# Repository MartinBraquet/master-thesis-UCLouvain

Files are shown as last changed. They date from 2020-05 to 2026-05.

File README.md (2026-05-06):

# Master's thesis at UCLouvain

### Design of an ultra-low-power energy-harvesting audio sensor for ecosystem monitoring

Here are the source files of my Master's thesis at UCLouvain (June 2020).

It includes all the simulations required for this work:
* **Audio processing**: C code for the microcontroller and Matlab code to process the data (plot the graphs) received from the board
* **BOM**: Excel file with the bill of materials
* **IV mic**: Matlab code to plot the IV curves (current/voltage) of different microphones
* **Microcontroller**: Wisebatt simulation to provide a rough estimate of the whole system power consumption
* **Microphone**: LTspice and Matlab codes for the microphone/AFE subsystem (AC and noise)
* **PCB**: KiCad and Eagle files for the PCB design (schematic and PCB layout)
* **Power management**: Matlab and Excel files for measurements about the supercapacitor, solar cells, PMU and luminosity
* **Thesis source code**: LaTeX source code of the Master's thesis

Picture of the final model (with MCU/RF board)
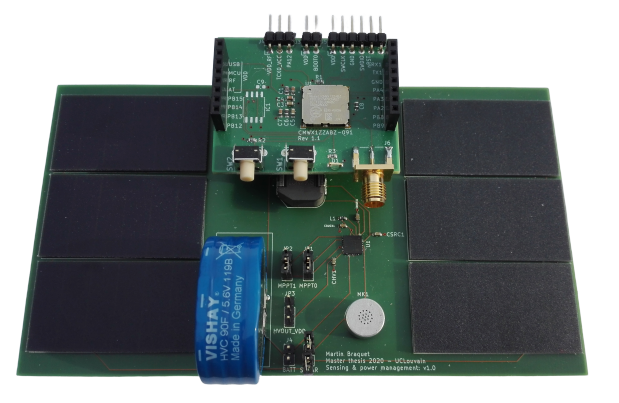
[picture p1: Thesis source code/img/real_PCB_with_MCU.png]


Precise spectrogram of the great tit song (from a bird song database)
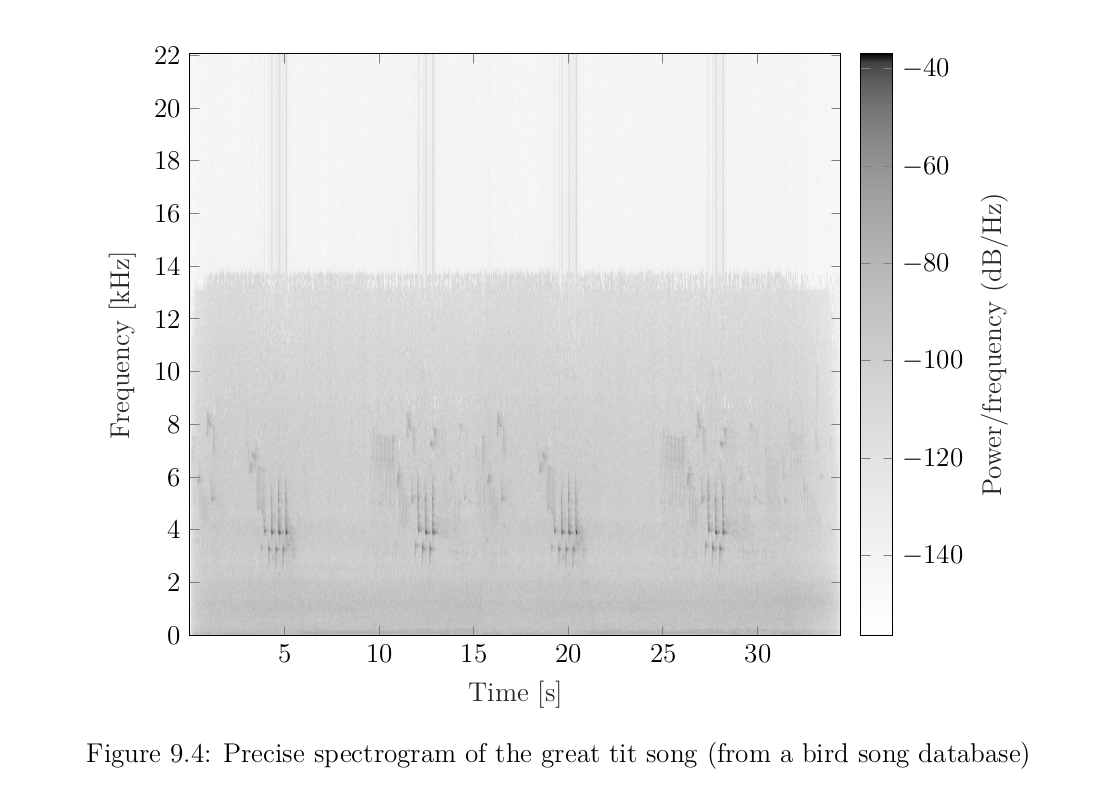
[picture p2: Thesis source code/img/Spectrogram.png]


Comparison of input-referred noise and current consumption for several operational amplifiers
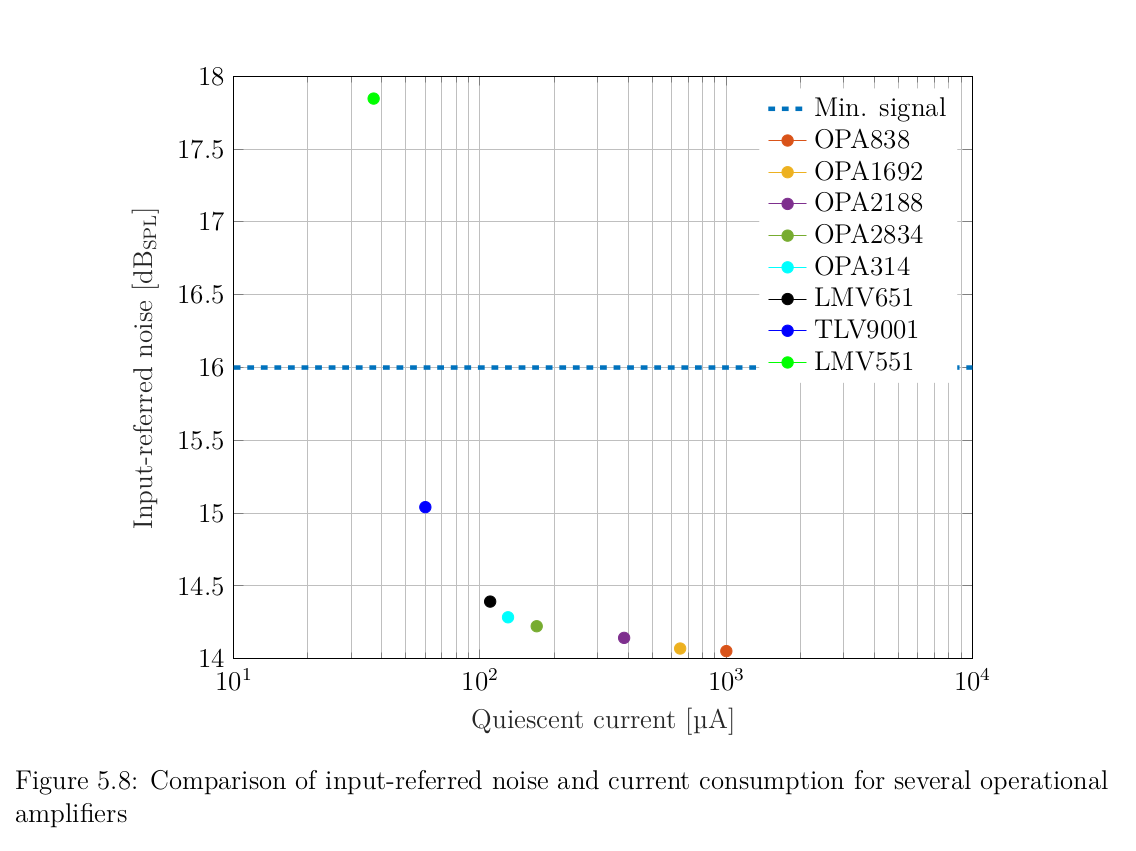
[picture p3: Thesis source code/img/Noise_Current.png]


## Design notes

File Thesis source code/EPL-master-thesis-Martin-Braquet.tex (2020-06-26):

% EPL master thesis covers template
\documentclass{EPL-master-thesis-covers-EN}

\usepackage{parskip}
\usepackage{siunitx}
\usepackage{float}
\usepackage{textcomp}
\usepackage{amsmath}
\usepackage{multirow}
\usepackage{subcaption}
\usepackage{pgfplots}
\usepackage{mathtools}
\usepackage{booktabs}
\pgfplotsset{compat=1.15}
\usepackage[hidelinks]{hyperref}
\definecolor{lttotitextcolor}{rgb}{0, 0.4, 0.25}
\usepackage{natbib}
\pdfoptionpdfminorversion=7

\graphicspath{{img/}}

\newgeometry{top=3cm,bottom=3cm,left=2cm,right=2cm}

\usepackage[americanresistors, RPvoltages, american voltages]{circuitikz}
\tikzstyle{sensor}=[draw, fill=blue!20, text width=5em, 
    text centered, minimum height=2.5em, rounded corners]
\tikzstyle{sensor2}=[draw, fill=green!20, minimum width=20em, 
    text centered, minimum height=2.5em, rounded corners]
\tikzstyle{sensor3}=[draw, fill=brown!20, text width=5em, 
    text centered, minimum height=2.5em, rounded corners]
\tikzstyle{sensor4}=[draw, fill=orange!20, text width=5em, 
    text centered, minimum height=2.5em, rounded corners]
\tikzstyle{empty_block}=[draw, minimum width=30em, 
    text centered, minimum height=12em, rounded corners]
\tikzstyle{empty_block2}=[draw, minimum width=10em, 
    text centered, minimum height=12em, rounded corners]
\tikzstyle{ann} = [above, text width=5em]
\tikzstyle{afes} = [draw, fill=red!20, text width=5em, 
    text centered, minimum height=2.5em, rounded corners]
\def\edgedist{2.5}

\usetikzlibrary{external}
\tikzexternalize
\tikzsetexternalprefix{tikz_figures/}

\newcommand{\parallelsum}{\mathbin{\!/\mkern-5mu/\!}}
\newcommand{\te}[1]{\textrm{#1}}
\newcommand{\tabitem}{~~\llap{\textbullet}~~}

\DeclarePairedDelimiter\floor{\lfloor}{\rfloor}

\newcommand\nnfootnote[1]{%
  \begin{NoHyper}
  \renewcommand\thefootnote{}\footnote{#1}%
  \addtocounter{footnote}{-1}%
  \end{NoHyper}
}

% Please fill in the following boxes
% Title of the thesis
\title{Design of an ultra-low-power energy-harvesting audio sensor for ecosystem monitoring}

% Subtitle - remove this line if not applicable
%\subtitle{Microphone design for biodiversity inventory in forest}

% Name of the student author(s)
\author{Martin \textsc{Braquet}\!\nnfootnote{\url{martin.braquet@hotmail.com}}}
%\secondauthor{Firstname \textsc{Lastname}}		% remove if not applicable
%\thirdauthor{Firstname \textsc{Lastname}}			% remove if not applicable

% Official title of the master degree (copy/paste from list below)
% Master [120] in Biomedical Engineering
% Master [120] in Chemical and Materials Engineering
% Master [120] in Civil Engineering
% Master [120] in Computer Science
% Master [120] in Computer Science and Engineering
% Master [120] in Cybersecurity
% Master [120] in Data Sciences Engineering
% Master [120] in Data Science: Information technology
% Master [120] in Electrical Engineering
% Master [120] in Electro-mechanical Engineering
% Master [120] in Mathematical Engineering
% Master [120] in Mechanical Engineering
% Master [120] in Physical Engineering
% Master [60] in Computer Science
% Specialised master in nanotechnologies
% Specialised master in nuclear engineering
\degreetitle{Master [120] in Electro-mechanical Engineering}

% Name of the supervisor(s)
\supervisor{David \textsc{Bol}}
\secondsupervisor{Ramin \textsc{Sadre}}		% remove if not applicable
%\thirdsupervisor{Firstname \textsc{Lastname}}		% remove if not applicable

% Name of the reader(s)
\readerone{Rémi \textsc{Dekimpe}}
\readertwo{Denis \textsc{Flandre}}			% remove if not applicable
%\readerthree{Firstname \textsc{Lastname}}			% remove if not applicable
%\readerfour{Firstname \textsc{Lastname}}			% remove if not applicable
%\readerfive{Firstname \textsc{Lastname}}			% remove if not applicable

% Academic year (update if necessary)
\years{2019--2020}

% Document
\begin{document}

% Front cover page
\hypersetup{pageanchor=false}

\maketitle

\begin{abstract}

The Internet of Things (IoT) is predicted to lead to the deployment of a very large number (possibly trillions) of connected smart sensors for various applications. Such a massive deployment of smart sensors is not environmentally sustainable if the smart sensors are replaced every two years because of the pressure they put on natural resources and the ecotoxicity of the e-waste they generate.

Furthermore, the rising climate change due to ecosystem destruction involves monitoring forests in order to analyze and preserve the ecosystem. Such monitoring is typically achieved manually via a person who samples data less than once a day, which fails to provide strong results and asks for human presence during data acquisition.

To solve these issues, the focus of this master thesis is on the development of an autonomous and efficient audio smart sensor continuously analyzing the forest ecosystem. To fulfill the energy constraints implied by its total autonomy, this sensor harvests energy from the environment through miniaturized photovoltaic cells sized according to the sun illuminance throughout days and seasons, using an environmentally-friendly and non-toxic supercapacitor to store energy.
With a 15+ year lifetime, this fully autonomous device operates at an optimized \SI{2.5}{V} supply voltage reaching \SI{22.1}{mW} of average power harvesting/consumption. An electret condenser microphone collects a signal as low as \SI{16}{dB_{SPL}} (compared to a \SI{14.22}{dB_{SPL}} input-referred noise), which is then amplified in the full frequency range of bird emission (\SI{20}{Hz} -- \SI{20}{kHz}) by a low-noise and low-power analog front-end. This signal is further processed in an ultra-low-power chip embedding a microcontroller, alternating between run and sleep modes with a $1/3$ duty cycle, and a transceiver optimized for IoT applications with LoRaWAN networks. 

The microcontroller detects sounds when birds are active (typically during the day for more than 12 hours) and ensures the radio-frequency communication at night depending on the supercapacitor voltage that is carefully monitored in real time. It sends information about the bird species encountered during the day, as well as their apparition frequency. In case of firmware update, this device receives the associated fragments when its energy is sufficient and it automatically changes the firmware with energy-optimized software requiring only \SI{10.6}{J} for the whole update.

By computing the weighted average frequency of the received sounds, the smart sensor is able to discriminate between four common birds in Belgium: the pigeon, blackbird, great tit and blue tit. For each species, several songs have been analyzed and used to train a $k$-nearest neighbors (KNN) classifier working in the real-time embedded system. Its precision, defined as the likelihood to find the correct species, reaches 94\% for songs coming from the previously learned database. For newly analyzed sounds, the detection algorithm performs likewise. More complex machine-learning algorithms could finally be further designed to discriminate between more species.

\end{abstract}

\renewcommand{\abstractname}{Acknowledgements}
\begin{abstract}

This thesis has been written throughout my last year at UCLouvain. It gave me the opportunity to have a first glimpse into an important work required for the procurement of a master's degree in engineering.  During this substantial work, I would like to thank the following people, starting with the most meaningful ones, for their important hints and source of motivation.

First of all, I would like to thank my main supervisor, Prof. D. Bol, for his precious advice. In his works, I deeply appreciated his way to approach a problem, starting with a technological/ecological/social need and then solving it by considering all the factors in the process (systemic approach). His maturity, sensibility and motivation to handle such problems made one of the most important marks on me throughout my studies at UCLouvain. 

Second, I would like to thank Tim Hess who wrote his thesis on a same topic but more focused on the wireless communication. We have had great collaborations to produce the final model of this work. He gave me important advice for the overall design and soldering of the PCB, more specifically on the handling of KiCad (a PCB design tool).

Third, I would like to thank the members of the ECS group\footnote{Electrical Circuits and Systems group led by Professors D. Bol and D. Flandre at UCLouvain.} and more specifically Rémi Dekimpe for his constant supervision through the year. He proved his availability at any time and had precious hints.

I would also like to thank my second supervisor, Prof. R. Sadre, for his availability. Likewise, I want to thank Prof. D. Flandre in advance for the reading of this thesis, as well as for his engaging courses given during my curriculum. More generally, I need to thank all the people who contributed to this work, e.g. for accessing the electronics lab and the ordering of the required materials.

\end{abstract}

\tableofcontents

\listoffigures

\listoftables

\newpage

\hypersetup{pageanchor=true}

\chapter{Introduction}

This thesis is dedicated to people interested in audio monitoring and its subsequent recent rise, as well as in the technical details/constraints related to the design of such sensors. It is accessible for people from diverse domains, but a background in engineering is nonetheless advised.

\section*{Context}

The Internet of Things (IoT) is a system of interrelated computing devices that are provided with unique identifiers and the ability to transfer data over a network without requiring human-to-human or human-to-computer interaction. It is predicted to lead to the deployment of a very large number (possibly trillions) of connected smart sensors for various applications. However, such a massive deployment of smart sensors is not environmentally sustainable if the smart sensors are replaced every two years because of the pressure they put on natural resources and the ecotoxicity of the e-waste they generate. Therefore, it is needed to fight obsolescence in the IoT domain by enabling a 10+ year lifetime for the smart sensors. 

\paragraph{Audio monitoring}

Forests are important sources for biodiversity and ecological balance. They provide many benefits and it is the main function for water and soil conservation, genetic resources for plant and animal, and also a source of wood supply and other forest goods. They also have important benefits on human physical and mental health~\cite{Meyer-Schulz}. However, recently the green forest environment has been interrupted by unethical activities such as development activities that decrease the benefits of the forest contribution.
Thus, in order to ensure long-term forest autonomy, it is important to implement a monitoring system that is responsible for providing effective monitoring for forest environment. Forest monitoring is not limited to environmental issues only, but it also includes fire monitoring and detection in forests~\cite{OTHMAN20121204}. To set the problems, a policy-relevant infrastructure for monitoring of forest ecosystems has been recently proposed in the European Union~\cite{ICP_Forests}.

Nowadays, some key variables, such as tree health and biodiversity, are only collected once a year because they must be assessed by a well-trained human operator. This low observation frequency considerably limits the possibility of characterizing evolution trends relating them with explanatory causes. 

To achieve this goal of an autonomous long-lasting sensor, energy needs to be harvested from the environment through miniaturized photovoltaic cells, using batteries whose chemistry does not wear out and having reconfiguration capabilities to keep up with application, security and communication protocol updates.

\section*{Contributions}

In this master thesis, a operational device is built to monitor bird songs in forest. It is attached to a tree, it records sounds, analyzes and sends them wirelessly. Thanks to a supercapacitor and solar cells, it is fully autonomous, efficient and connected to the cloud. It is in operation for more than 15 years without any human assistance and can discriminate between bird songs which are rather distinct (based on their frequency spectrum).

The objectives of this thesis are multiple. It first aims at improving the audio monitoring quality in forest while reducing human interactions, especially in areas with difficult access. Via this text, it also includes providing useful information for diverse people interested in the domain, such as companies willing to improve ecosystem monitoring or students facing a related problem.

For this purpose, all the files used for the simulations as well as the LaTeX source code of this thesis are fully open-source under the \textit{MIT} license\footnote{Provided that the reader gives appropriate credit, he is free to copy and redistribute the material in any medium or format under the same license as the original. He has permission to remix, transform, and build upon the material for any purpose, even commercially.} at \url{https://github.com/MartinBraquet/master-thesis-UCLouvain}.

\section*{Structure}

The structure of this thesis has been carefully built to replicate the design process of this sensor. Indeed, the chapters totally mimic the real chronology throughout the year, in such a way that each chapter is mainly based on the design choices of the previous chapters. 

Chapter 2 describes the use case, by detailing the state-of-the-art of audio monitoring, the requirements for the system and its general architecture.

Chapter 3 details the different types of energy storage, from the primary battery to the supercapacitor and the new developments. They are then compared and the most suited for this application is selected.  

Chapter 4 is dedicated to the power management. The selection of the supply voltage as well as the operation of the power management unit are explained.

Chapter 5 analyzes the sensing subsystem. After a brief review of the principles of wave propagation, different kinds of microphones are detailed and compared, leading to the selection of the most meaningful. Then, the analog front-end is detailed, associated with the design of each component. The best microphone is then chosen such that it optimizes the noise / power consumption specifications.

Chapter 6 gives a description of the data processing and transmission, with an emphasis on the microcontroller behavior.

Chapter 7 describes the power supply by first summarizing the whole power consumption. The best solar cells are then selected in accordance with the expected sun illuminance. The supercapacitor is characterized and its capacitance is designed according to the power management unit specifications.

Chapter 8 details the final model, with its design and prototyping, and ends with a complete validation of the system.

Chapter 9 provides different inference algorithms used to process, inside the microcontroller, the received data from the microphone. Experimental results are provided and reviewed.

Chapter 10 gives some perspectives of improvement for an application which is still new with great perspectives.

Chapter 11 ends this work with a conclusion. The appendices give additional details on the transimpedance amplifier, the noise gain of the microphone amplifier and the PCB layout/schematic of the final model.

\chapter{Use case}

This chapter describes a few state-of-the-art IoT smart sensors for forest monitoring and the process/systems required to accomplish the aforementioned goals.

\section{State of the art of IoT sensors for forest monitoring}

Since 2000, \textit{wireless sensor networks} (WSNs) have received increasing attention in research on automatic natural environments~\cite{Akyildiz}. 

For forest monitoring, research has already been achieved as attested by the following state of the art. First, in \cite{Granados}, they worked on autonomous recording units which have been widely used in a large number of bird studies in recent years, but challenges remain in estimating abundance based on acoustic monitoring. They tested whether vocal activity rate index (VAR; the number of songs per unit time for a species), recorded using autonomous recording units, was related to population abundance in two terrestrial bird species. Second, in \cite{Huanqi}, they illustrate a forest monitoring system solution of wireless sensor networks based on ZigBee by using sensor nodes and coordinator nodes. Third, in \cite{Jiang}, a 20-day wireless sensor network of 18 nodes has been deployed in a mountain area. It has a good fidelity since they received 87\% of sent sample data. Their primary concern remains to enlarge the network scale and prolong the network lifetime.

However, these previous works show that the use of WSNs has been limited to simple tasks due to key technological issues. First, the high power consumption of the sensor nodes in operation leads to a trade-off between the density of the sensor deployment (limited by the frequency of battery replacement by an operator) and the complexity of the ecosystem parameters to monitor. Second, the limited range of low-power wireless communication prevented large-scale deployment. Third, the monitoring of complex, non-directly observable parameters (e.g. bird population, tree health) is impeded by the lack of low-power algorithms (typically machine learning) that would process on-chip data. However, today, technological advances in ultra-low-power processors~\cite{8662293}, IoT communications and artificial intelligence open new possibilities. A brief insight of them will be described in this work.

\paragraph{Communication}

In regard to these topics, low power communication protocols also appeared. There is a trade-off between energy and range that such devices can sustain. The data rate, i.e. the amount of data transmitted per unit of time, can be tuned as a degree of freedom to adjust this trade-off. It is thus desirable to produce reconfigurable solutions.

For long-range communications, a low-power wide-area network (LPWAN) such as LoRa is used. LoRa is a spread spectrum modulation technique derived from chirp spread spectrum (CSS) technology and is the first low-cost implementation of chirp spread spectrum for commercial usage. LoRa also has a lot of applications in urban areas, such as waste management in smart cities~\cite{Cerchecci}.

For short-range communications, a wireless personal area network (WPAN) such as Bluetooth low energy (BLE) is used since they consume less energy per bit sent (\SI{30}{nJ/bit} compared to \SI{1}{\micro J/bit} for LoRa~\cite{Local_Sensor_Data_Processing}). For this, multiple challenges exist such as spectrum congestion (due to the limited data rate), data deluge, security flaws, natural resources, ecotoxicity, battery charging/replacement. Multi-hop transfer describes communications between several sensors, they can help solve some of these issues by increasing the range but with a costly synchronization~\cite{bol2018}.

\paragraph{Data processing}

With the limited data rate of low-power communication protocols, local data storage and processing are required to extract and store meaningful information.

In addition to on-chip data processing, edge computing has been proposed to further reduce the data flow and hence the power consumption, it refers to the enabling technologies allowing computation to be performed at the edge of the network, on downstream data on behalf of cloud services and on upstream data on behalf of IoT services~\cite{Shi2016}. Here, edges are any computing and network resources along the path between data sources and cloud data center (e.g. for forest monitoring, a gateway between the smart sensors and the cloud data centers). 

For sound analysis, some algorithms such as Blind Audio Source Separation (BASS) have been developed to discriminate the sound from several sources (e.g. birds) with the help of several sensors (that is, microphones). Methods exist to rank existing BASS algorithms according to their performance on the same test data~\cite{Vincent2006}.

\section{General architecture}

The general architecture of this type of sensor node is given in Figure~\ref{fig:general_architecture}. A sensor is a device which probes, processes and sends diverse physical subjects in an environment. For this work, the physical subject is the sound pressure.

Inside the sensor node, there are typically four submodules:
\begin{itemize}
 \item \textit{Sensor}: The sensor captures data from its environment by producing a measurable response to a change in a physical condition like temperature or pressure. It has specific characteristics such as accuracy, sensitivity\dots ~The physical signal is typically filtered and amplified in an analog front-end (AFE). The continual analog signal is then sent to a controller for further processing, either in continuous form or in digital form via an analog-to-digital converter (ADC).
 \item \textit{Controller}: The data are processed in a controller, which is most often a microcontroller for its flexibility to connect to other devices, ease of programming, low cost and low power consumption. The microcontroller performs tasks, processes data and controls the functionality of other components in the sensor node.
 \item \textit{Transceiver}: The transmission (TX) and reception (RX) are combined in a transceiver which allows exchanging data, mostly wirelessly through radio frequency (RF) with an antenna. WSNs tend to use license-free communication frequencies\footnote{The ISM radio bands are portions of the radio spectrum reserved internationally for industrial, scientific and medical (ISM) purposes other than telecommunications.}, LoRa uses for example license-free sub-gigahertz radio frequency bands (like 433 MHz, 868 MHz (Europe)) enabling long-range transmissions with low power consumption.
 \item \textit{Power management}: Since the wireless sensor node is often placed in a hard-to-reach location, changing the battery regularly can be costly and inconvenient. Hence, an important aspect in the development of a wireless sensor node is ensuring that there is always adequate energy available to power the system. The sensor node consumes power for sensing, data processing and communicating. Power is stored either in batteries or capacitors. They renew their energy from solar sources, radio frequency, temperature differences, or vibration.
\end{itemize}

\begin{figure}[H]
\centering
\scalebox{0.9}{
\begin{tikzpicture}
    \node (afe) [afes] {Sensor};
    \path (afe.0)+(-6,0) node (mic) [sensor4] {Sound,\dots};
    \path (afe.0)+(3,0) node (proc) [sensor] {Controller};
    \path (afe.0)+(6.5,0) node (tx) [sensor3] {Transceiver};
    \path (afe.0)+(3,2) node (pw) [sensor2] {Power management};
    \path (afe.0)+(2.7,1) node (mysensor) [empty_block] {};
    \path (afe.0)+(-6,1) node (envi) [empty_block2] {};
    \node[anchor=north west,inner sep=10pt] at (mysensor.north west)
    {\textbf{Sensor node}};
    \draw (afe.0)+(-6,0.5) circle (50pt);
    \node[anchor=north west,inner sep=10pt] at (envi.north west)
    {\textbf{Environment}};
    \path [draw, ->] (mic) -- node [above] {} (afe.west |- mic) ;
    \path [draw, ->] (afe.east) -- node [above] {} (proc.west |- afe) ;
    \path [draw, <->] (proc.east) -- node [above] {} (tx.west |- proc) ;
    \draw (tx.0) -- (11,0) -- (11,1) ;
    \node[] at (-4.8,1) {Physical subject};
    \foreach \r in {.1,.2,.3}
      \draw (11.1,1) ++ (60:\r) arc (60:-60:\r);
\end{tikzpicture}}
\caption{Block diagram of a general IoT sensor node}
\label{fig:general_architecture}
\end{figure}

Because energy is the most important scarcity in such sensors (defining its lifetime), one has to keep in mind the power consumption of each block throughout the design. It is expected that the parts with the most power consumption are the microcontroller, the transceiver and the microphone. The other parts will be designed to be negligible compared to the formers.

\section{Requirements analysis}
\label{section:requirements}

The sensor that will be produced needs to fit the following requirements:

\begin{itemize}
 \item The microphone detects sounds up to \SI{50}{m} in order to produce a reasonable inventory of bird population.
 \item It is able to communicate wirelessly by receiving and transmitting data under power constraints.
 \item Based on the continuously received sound, the sensor has to discriminate the bird species among a small group (4) of selected birds.
 \item The lifetime is one of the most important demands for this application, the sensor has to work fully autonomously (day and night) for at least 15 years.
 \item The materials used for the design, particularly the energy storage element, must have low toxicity.
 \item The device cannot be invasive and should be easy to install. The total volume must not exceed \SI{200 x 200 x 55}{mm} to respect the forest ecosystem and be easily placed on a tree. The main part of the volume will be due to the storage element and the solar cells.
 \item For a massive deployment, the cost cannot exceed 15 euros.
\end{itemize}

%\textcolor{green}{Schema de flow (déroulement du mémoire)}

\chapter{Energy storage}

Energy storage has an important role in sensor applications. First, this role can be identified as either a unique power for the application, or as a temporary storage of energy provided by the energy harvester. In the framework of this thesis, the latter is considered since solar cells (energy harvester) will bring energy to the system, which is stored in an energy storage element.

Then, one has to characterize the main figures of merits such as the energy density, the maximum self-discharge and application conditions, as well as financial and environmental considerations.

A Ragone plot is typically used for comparing the energy density of various energy-storing devices. On such a chart, the values of specific energy density (in \si{Wh/kg}) are plotted versus specific power density (in \si{W/kg}). In Figure~\ref{fig:ragone_plot}, one can see the trade-off between energy density and power density. From fuel cells to supercapacitors by way of Li-ion batteries, energy density is decreasing in aid of power density.

\begin{figure}[H]
    \centering
    
    \caption[Ragone plot showing specific energy versus specific power for various energy-storing devices]{Ragone plot showing specific energy versus specific power for various energy-storing devices~\cite{Service902}}
    \label{fig:ragone_plot}
\end{figure}

In order to answer the previous requirements, common energy storage types are analyzed and the most suited type for this work is detailed.

\section{Primary batteries}

Primary batteries are non-rechargeable, they thus have only one life cycle. However, they can sometimes still have their place in IoT applications when the power consumption and the sensor lifetime are particularly reduced. Primary batteries are mainly based on three technologies.

\subsection*{Zn-MnO${}_{\textbf{2}}$ batteries}

Zn-MnO${}_2$ batteries are composed of a combination of metallic zinc (oxidation) and a manganese dioxide electrode (reduction). They exist under the form of zinc-carbon cells and alkaline batteries and differ according to the electrolyte inside.

The voltage window is between \SI{0.9}{V} and \SI{1.5}{V}. The energy density of a typical AA (approximately \SI{8}{cm^3}) zinc-carbon cell is \SI{100}{mWh/cm^3}, whereas a commercial alkaline cell reaches at present up to \SI{400}{mWh/cm^3}~\cite{doi:10.1002/er.2949}.

These batteries are very well known and low cost, but present a high self-discharge rate.

\subsection*{Lithium primary batteries}

Lithium primary batteries have an anode made of metallic lithium and a cathode made of several materials such as MnO${}_2$ or FeS${}_2$.

Batteries integrating MnO${}_2$ commonly deliver a total cell voltage of around \SI{3}{V}. These batteries work with the oxidation of lithium and reduction of manganese, with a typical energy density of \SI{650}{mWh/cm^3}.

The second type of lithium battery is based on FeS${}_2$. It has a practical voltage of \SI{1.5}{V} and is therefore compatible with alkaline and zinc-carbon cells. It has an energy density of approximately \SI{550}{mWh/cm^3}.

Overall, it is able to deliver high currents and has a quite flat voltage profile upon discharging. Moreover, it performs well at low temperatures and has a significantly lighter weight than alkaline cells.

\subsection*{Zn-air batteries}

Zn-air batteries are a class of batteries that employ metallic zinc particles as its anode and an aqueous liquid electrolyte. With a voltage of \SI{1.4}{V}, this
battery is commercially available as button cells with an energy density of around \SI{1500}{mWh/cm^3}.

Other disadvantages of this type of battery are that the catalyst that is required for the reduction of oxygen usually consists of expensive noble metals and that the battery is unable to deliver high peak currents. This type of battery is therefore commonly used in applications where only low
currents are required from a battery with a small volume~\cite{doi:10.1002/er.2949}.

\section{Secondary batteries}

Secondary batteries are rechargeable, they thus have a certain number of life cycles (usually more than 500). Only battery types that are suitable for the IoT domain are presented in this thesis.

\subsection*{Batteries with liquid or polymer gel electrolytes}

\subsubsection*{Nickel metal hydride batteries}

Nickel metal hydride batteries (NiMH) combine nickel at the positive electrode and hydrogen (metal hydride) at the negative electrode.  During discharge, a proton, obtained from the electrolyte, occurs in reduction of nickel oxyhydroxide. The loss of protons in the electrolyte produces hydroxide anions which will recombine with a proton from the metal hydride.

The cells typically work at around \SI{1.2}{V}, allowing interchangeability with alkaline batteries. However, they have a higher self-discharge rate and a narrow temperature window (0 to \SI{45}{\degree C}). The energy density is around 250 and \SI{380}{mWh/cm^3}.

\subsubsection*{Li-ion batteries}

Lithium-ion batteries are composed of lithium metal oxide at the positive electrode (LiCoO${}_2$) and a material storing lithium in a neutral form such as graphite at the negative electrode. The charge process is based on the motion of lithium ions from the metal oxide to the electrolyte, where they are stored in graphite.

Compared to NiMH batteries, they have higher energy density (between 300 and \SI{500}{mWh/cm^3}), lower self-discharge rate and larger temperature window (-20 to \SI{60}{\degree C}). They are however easily damaged in case of overdischarging or overcharging, thus requiring a special protective electric circuit for the power management.

Overall, liquid electrolytes (both NiMH and Li-ion) have high volatility and have been the source of explosions in lithium batteries. Research thus has been done on the design of solid electrolytes.

\subsection*{Solid-state batteries}

Solid-state batteries use solid electrodes and a solid electrolyte, such as ceramics (e.g. oxides, sulfides, phosphates) or a solid polymer. They are potentially safer than batteries with liquid electrolytes, with higher energy density, but at a much higher cost.
However, these efforts have faced a number of issues.

One of the biggest problems is that when the battery is charged up, atoms accumulate inside the lithium metal, causing it to expand. These repeated changes in the metal’s dimensions make it difficult for the solids to maintain constant contact, and tend to cause the solid electrolyte to fracture or detach.

Another problem is that none of the proposed solid electrolytes are truly chemically stable while in contact with the highly reactive lithium metal, and they tend to degrade over time.

\section{Supercapacitors}

Supercapacitors are high-capacity capacitors storing energy in an electric field, rather than in a chemical reaction, like batteries. This allows high power density for short-term energy storage\footnote{They can provide very high currents during a short time.}, almost instant recharging and very long lifetimes. Made of porous carbon (electrodes) and liquid salts (electrolyte)~\cite{BAPTISTA20191153}, they are not composed of harmful\footnote{Failing in a nice way, they will never overrun or start a fire.} chemicals or toxic metals.
Since the supercapacitor is non-chemical, the voltage is free to rise until the dielectric fails (often in the form of a short circuit). It is thus needed to avoid going higher than the specified voltage, which is characterized by a lower voltage limit than for batteries.

Due to their behavior in between electrolytic capacitors and batteries, they are particularly well suited for IoT applications. Indeed, they typically store 10 to 100 times more energy per unit volume or mass than electrolytic capacitors. They can also accept and deliver charge much faster than batteries, and tolerate many more charge and discharge cycles than rechargeable batteries. Nevertheless, care needs to be paid to their significant leakage current which is proportional to the capacitance of the supercapacitor.

Instead of using a conventional solid dielectric, supercapacitors use electrostatic double-layer capacitance and electrochemical pseudocapacitance~\cite{2019JPS...414..420B}.

\subsection*{Electrostatic double-layer capacitors}

Electrostatic double-layer capacitors (EDLCs) are the most common type of supercapacitors. They use carbon electrodes or derivatives with much higher electrostatic double-layer capacitance than electrochemical pseudocapacitance, achieving separation of charge in a Helmholtz double layer at the interface between the surface of a conductive electrode and an electrolyte.

\subsection*{Electrochemical pseudocapacitors}

Electrochemical pseudocapacitors use metal oxide or conducting polymer electrodes with a high amount of electrochemical pseudocapacitance additional to the double-layer capacitance. They store charge chemically through redox reactions where one species transfers electrons to another, similar to a battery. While pseudocapacitors store more energy, their widespread use has been hampered by their narrow electrochemical voltage window, which is the voltage range where the electrode materials are stable.

Additionally, there exist hybrid capacitors, such as the lithium-ion capacitors, using electrodes with different characteristics: one exhibiting mostly electrostatic capacitance and the other mostly electrochemical capacitance.

\section{New developments}

Promising new methods are also developed in research laboratories, some of them are detailed hereafter.

\subsection*{3D electrodes for electrochemical energy storage}

Superior energy or power density for batteries is typically achieved only in ultra-thin electrodes with low mass loadings. To realize the full potential of these electrode materials, new electrode architectures allow more efficient charge transport beyond the limits of traditional electrodes. Working on the design and synthesis of 3D electrodes is promising to address charge transport limitations in thick electrodes. Such 3D porous architectures could enable composite electrodes with an unprecedented combination of energy and power densities~\cite{Sun2019}.

In addition to the recent development of Li-ion batteries with  flexible, bendable, or foldable characteristics, some research has been focused on batteries with advanced features of stretchability in which the systems are able to accommodate large mechanical strain and still maintain their functions. Such sponge-inspired electrodes for stretchable Li-ion batteries show no specific capacity reduction when bent, unlike the cells using conventional electrodes~\cite{doi:10.1002/adma.201505299}.

\subsection*{Lithium metal anode}

Recent research has been achieved on lithium metal anodes that could improve the longevity and energy density of future batteries~\cite{10.1038/s41586-020-1972-y}.

Most attempts to overcome the problems of solid-state batteries have focused on designing solid electrolyte materials that are absolutely stable against lithium metal, which turns out to be difficult.  Instead, some researchers adopted an unusual design that utilizes two additional classes of solids, ``mixed ionic-electronic conductors'' (MIEC) and “electron and Li-ion insulators” (ELI), which are absolutely chemically stable in contact with lithium metal. 

They developed a three-dimensional nanoarchitecture in the form of a honeycomb-like array of hexagonal MIEC tubes, partially infused with the solid lithium metal to form one electrode of the battery, but with extra space left inside each tube. When the lithium expands in the charging process, it flows into the empty space in the interior of the tubes, moving like a liquid even though it retains its solid crystalline structure. This flow, entirely confined inside the honeycomb structure, relieves the pressure from the expansion caused by charging, but without changing the outer dimensions of the electrode or the boundary between the electrode and electrolyte. The other material, the ELI, serves as a crucial mechanical binder between the MIEC walls and the solid electrolyte layer.

\section{Shape}

In addition to the electrical and thermal characteristics, the form of the storage element is particularly important for IoT devices where the full sensor size is often limited. The main trade-off thus appears between the charge capacity and the size of the energy storage element.

The main shapes of micro-batteries are button cells, pouch cells and thin film batteries.

\section{Comparison}

Table~\ref{tab:comparison_energy_storage} presents the main figures of merit for the previously described types of energy storage.

\begin{table}[H]
\centering
\scalebox{0.655}{
\begin{tabular}{l|ccc|ccc}
\toprule
                          & \multicolumn{3}{c|}{Capacitors} & \multicolumn{3}{c}{Batteries} \\ \midrule
                          & Ceramic & Electrolytic & Supercap & Non-rechargeable & \multicolumn{2}{c}{Rechargeable} \\
                          &  &  & EDLC & Alkaline & NiMH & Lithium ion \\ \midrule
 Power density [W/g]      &  & > 100 & 2 -- 10 &  & 2.5 -- 10 & 1 -- 3  \\
 Energy density [mWh/g]   & 0.1~\cite{DEKIMPE20198} & 0.01 -- 0.3  & 5 &  & 60 -- 120  & 120 -- 240 \\
 Self-discharge rate [per month]     & 100\% & \SI{100}{h} & 50\% & < 0.3\% & 0.08 – 2.9\% & 5\% \\
 Leakage current          & 1 -- 100 \si{nA/\micro F}  &  & 2 -- 5 \si{fA/\micro F}~\cite{DMF3Z5R5H474M3DTA0}~\cite{Vishay} &  &  & 5 \si{\micro A}~\cite{DEKIMPE20198} \\
 Service life [years]     & 25~\cite{DEKIMPE20198} & 15 & 10 -- 15 & 5 -- 10 &  & 5 --10 \\
 Life cycles              & unlimited~\cite{DEKIMPE20198} & unlimited & \SI{1000000}{} & 1 & 180 -- 2000 & 500 \\
 Degradation              & negligible &  & -80\% in 10 years &    &  & -50\% in 500 cycles     \\
 Charge time              &    &  & 1 -- \SI{10}{s} &    &  & 10 -- \SI{60}{min}     \\
 Cell voltage [V]             &    & 4 -- 630 & 2.3 -- 2.75 & 1.5   & 1.2 & 3.6     \\
 Charge T° [\si{\degree C}] &  & -40 -- 70 & -40 -- 65 & & & 0 -- 45 \\
 Discharge T° [\si{\degree C}]             &  & -40 -- 70 & -40 -- 65 & & & -20 -- 60 \\
 Discharge efficiency     &   & 99\% & 95\% &    & 66\% -- 92\% & 90\%     \\
 Toxicity                 &    &  & low &    &  & middle \\ \bottomrule
\end{tabular}
}
\caption{Comparison of various types of energy storage}
\label{tab:comparison_energy_storage}
\end{table}

In this table, the life cycle is the number of complete charge/discharge cycles that the battery is able to support before its capacity falls under 80\% of its original capacity.
Although the deployment of such sensors would imply the fabrication of several thousands of energy storage elements, the impact of the toxicity is small for such projects lasting more than 20 years without replacement. The degradation corresponds to the decrease of its maximum energy storage throughout its life.

Another factor of merit is the overall efficiency, which is computed as
\[
 \eta = \frac{E_\te{O}}{E_\te{I}}
\]
where $E_\te{O}$ is the energy delivered during the whole life of the energy storage element, and $E_\te{I}$ is the total energy fed to the storage element, composed of both the fabrication energy and the recharge energy. It is difficult to compute this efficiency due to the lack of information about the fabrication energy (typically not given by manufacturers). However, Li-ion batteries (\SI{50.17}{kWh/kg} for electric vehicles~\cite{manufacturing_lithium}) generally require more manufacturing energy than supercapacitors.

\subsection*{Criticality}

To assess the criticality of energy storage elements, one needs to consider the environmental and societal impacts combined with their scarcity. The scarcity of an element is assessed by the variation of its availability on Earth between the past decades and nowadays (not to be confused with rare-earth elements which are not critical). They include components overused for electronic devices such as copper, gold, silver, lithium and cobalt.

For Lithium-ion and NiMH batteries, the following compounds are used:
\begin{itemize}
 \item Positive electrode: metal oxide compounds such as lithium extracted from brine or rock, nickel, cobalt, hydrogen-absorbing alloy (nickel alloys with many metals: V, Ti, Zr, Ni, Cr, Co, Al and Fe)
 \item Negative electrode: graphite (carbon-based)
 \item Electrolyte
\end{itemize}

One can thus see that many critical and polluting compounds appear in the positive electrode.

For EDLCs, the following compounds are used:

\begin{itemize}
 \item Electrodes: porous carbon (activated carbon, carbon nanotubes and carbon aerogels) built from graphite \cite{Hastak}
 \item Electrolyte: liquid salts (water with ions)
 \item Polymeric membrane forming a microporous layer as separator
\end{itemize}

Supercapacitors are thus mainly built from carbon, one of the most abundant elements on Earth. They are far less toxic and resource-intensive than metal-based batteries.

\section{Selection}

Building upon these results, a supercapacitor is chosen because of its high lifetime, low toxicity, low criticality and reasonable energy density. As detailed in the Ragone plot (Figure~\ref{fig:ragone_plot}), this energy storage element can deliver high currents but stores less energy per volume. Its substantial leakage current is also needed to be further taken care of. The sizing of this supercapacitor will be achieved in Chapter~\ref{supercap_sizing} once the whole power consumption is fully determined. 

%Approx energy available based on normal volume of supercap -> guideline through the design -> compared with this value and check that small parts draw less than 1 percent of this energy.

\chapter{Power management}

The purpose of power management is to harvest energy from solar cells, store it in a supercapacitor, and deliver it to the circuit through a stable voltage supply. In this section, the best supply voltage is determined and the power management unit is explained.

\section{Operating voltage design}
\label{section:operating_voltage}

First, the supply voltage is used to power the sensing subsystem and the MCU/transceiver chip. For practical and energy efficiency reasons, the same supply voltage is selected for the whole system.

Since the microcontroller uses a low-dropout (LDO) regulator to regulate its internal voltage, the current consumption is independent from the supply voltage. In order to minimize the power consumption, one thus needs to use the lowest supply voltage. However, using a low supply voltage decreases the AFE amplification gain and therefore the precision (i.e. the signal-to-noise ratio) on the microphone signal that will be read at the input of the MCU. Indeed, while the noise at the sensing output is roughly independent from the amplification gain of the sensing subsystem (see the proof in Section~\ref{section:AFE}), the signal power is reduced with the gain. Hence, this trade-off leads to the selection of a \SI{2.5}{V} supply voltage which lies in the \SI{2.2}{V} -- \SI{3.6}{V} range of the CMWX1ZZABZ chip.

%the resolution of an $N$-bit ADC is given by $V_\te{DD}/2^N$ where $V_\te{DD}$ is the supply voltage.

\section{Power management unit}
\label{section:PMU}

A power management unit (PMU) is an integrated energy management circuit that extracts DC power from solar cells to simultaneously store energy in a rechargeable element and supply the system with independent regulated voltages. An AEM10941 chip from e-peas is selected because of its ultra-low power consumption and the close relations between the university and the company (see Figure~\ref{fig:AEM10941}).

\begin{figure}[H]
    \centering
    
    \caption[AEM10941 simplified schematic view]{AEM10941 simplified schematic view~\cite{AEM10941}}
    \label{fig:AEM10941}
\end{figure}

Its characteristics are given in Table~\ref{tab:AEM10941}, by only considering the high voltage regulator. The very low quiescent current is nearly independent from the supercapacitor voltage.

\begin{table}[H]
\centering
\scalebox{1}{
\begin{tabular}{lc}
\toprule
 Max input current                       & \SI{110}{mA}               \\
 Max input voltage                       & \SI{5}{V}                  \\
 Output voltage                          & \SI{1.8}{V} -- \SI{4.1}{V} \\
 Max output current                      & \SI{80}{mA}                \\
 Max supercap charge                     & \SI{4.5}{V}                \\ 
 Min dropout supercap -- output voltage & \SI{0.3}{V}                \\ 
 Quiescent current                       & \SI{0.6}{\micro A}         \\ \bottomrule
\end{tabular}
}
\caption{Characteristics of the AEM10941 PMU}
\label{tab:AEM10941}
\end{table}

\subsection*{Storage element and LDO configuration}

Configuration pins determine various operating modes by setting predefined conditions for the energy storage element (overcharge or overdischarge voltages) and by selecting the voltage of the high-voltage supply and the low-voltage supply.
The low-voltage supply is not used and the high-voltage supply is set to \SI{2.5}{V}. These characteristics correspond to a preset state in the chip, which helps reduce internal losses by not using additional resistors to select a custom configuration. The three configuration pins CFG[2], CFG[1] and CFG[0] are thus set to 0, 1 and 1, corresponding to the charge of a dual-cell supercapacitor charged in the range \SI{2.8}{V} -- \SI{4.5}{V} in order to power the low-voltage and high-voltage supplies at \SI{1.8}{V} and \SI{2.5}{V}, respectively.

Additionally, three status pins allow monitoring the PMU, whose one informs about supercapacitor overdischarge. For a first prototype, connecting this pin to a LED can be useful to deduce the supercapacitor state, but it is not used in the final model to further reduce power consumption (which is non-negligible for typical LEDs, around \SI{1}{mA}).

\subsection*{Maximum power point tracking}

The efficiency of power transfer from the solar cell depends on both the amount of sunlight arriving on the solar cells and the electrical characteristics of the load. As the amount of sunlight varies, the load characteristic that produces the highest power transfer efficiency changes, so that the efficiency of the system is optimized when the load characteristic changes to keep the power transfer at highest efficiency. 
Maximum power point tracking (MPPT) is thus used by the PMU by means of a boost converter regulating its input voltage so that the electrical current that enters the boost converter yields the best power transfer from the harvester under any ambient conditions (see Section~\ref{section:solar_cells} for more details about the intrinsic principle of solar cells).

This PMU uses the open-circuit voltage algorithm, the simplest MPPT control method. It consists to set the voltage at a constant ratio of the open-circuit voltage $V_\te{OC}$. By temporarily disconnecting the source from the PMU, the MPPT module maintains knowledge of $V_\te{OC}$. It then sets the MPPT voltage at $V_\te{MPPT}$ depending on $V_\te{OC}$ and the ratio (70\%, 75\%, 85\% or 90\%) selected in hardware via two headers connected to the configuration pins. A typical MPPT ratio leading to the maximum power is 76\%~\cite{10.1109/ICSTE.2010.5608868}, but it will be refined experimentally in the validation section. Still, the main disadvantage of this method is that there is momentary power loss due to the disconnection of the load from the solar cells for the sampling of its open-circuit voltage.

\subsection*{Boost conversion efficiency}

The energy converted from the solar cells to the supercapacitor (called boost voltage) is not fully converted due to the internal boost converter efficiency. As depicted in Figure~\ref{fig:boost_efficiency} for a typical harvested current of \SI{10}{mA}, the efficiency is maximum when the input voltage $V_\te{SRC}$ is \SI{0.4}{V} below the output voltage $V_\te{BOOST}$ (see Table~\ref{tab:max_eff_PMU}).

\begin{figure}[H]
    \centering
    
    \caption{Boost conversion efficiency (solar cells -- supercap) of the AEM10941}
    \label{fig:boost_efficiency}
\end{figure}

\begin{table}[H]
\centering
\begin{tabular}{ccc}
\toprule
 $V_\te{SRC}$ & $V_\te{BOOST}$ & Efficiency \\ \midrule
 \SI{2.2}{V}  & \SI{2.6}{V}    & 92\%      \\
 \SI{3.2}{V}  & \SI{3.6}{V}    & 95\%      \\
 \SI{3.7}{V}  & \SI{4.1}{V}    & 96\%      \\ \bottomrule
\end{tabular}
\caption{Values of maximum efficiency for the src -- boost conversion with a \SI{10}{mA} input current}
\label{tab:max_eff_PMU}
\end{table}

Since the source voltage impacts both the boost conversion efficiency and the harvested power (see previous paragraph), the optimal source voltage needs to be determined. Based on Figure~\ref{fig:boost_efficiency}, the efficiency significantly falls when the source voltage exceeds its optimal voltage. The source voltage thus needs to stay below $V_\te{BOOST} - \SI{0.4}{V}$ at all times, corresponding to \SI{2.4}{V} for this work (supply voltage of \SI{2.5}{V} implying a supercap voltage of at least \SI{2.8}{V}). In this case, it is thus expected to reach a boost efficiency of 92\% whatever the supercap voltage. Finally, the maximum source voltage set to \SI{2.4}{V} might be slightly relaxed if the IV curve of the solar cells provide a significant power increase at a higher source voltage (see Section~\ref{section:solar_cells}).

\subsection*{High-voltage LDO regulation}

As shown in Figure~\ref{fig:LDO_voltage}, the PMU supply voltage depends on the load current drawn by the sensing and MCU/RF subsystems. It decreases from \SI{2.5}{V} without load to \SI{2.43}{V} at the maximum load (that is, \SI{80}{mA}). Although this voltage variation might impinge upon the signal reading at the ADC input of the microcontroller, no voltage regulation needs to be taken into account inside the MCU code. Indeed, both the signal voltage $V_\te{in,ADC}$ from the microphone and the ADC supply voltage $V_\te{DD}$ vary likewise, this leads to the same digitized number $\floor{V_\te{in,ADC}/V_\te{DD}}$.

\begin{figure}[H]
    \centering
    
    \caption{High-voltage LDO regulation at \SI{2.5}{V} in function of the load current}
    \label{fig:LDO_voltage}
\end{figure}

Finally, the LDO efficiency can be simply calculated as $V_\te{out}/V_\te{in}$ (same input -- output current) if the quiescent current (\SI{0.6}{\micro A}) can be neglected with regards to the output current. The hyperbolic curve in Figure~\ref{fig:LDO_efficiency} confirms the $1/V_\te{in}$ dependence of the efficiency on $V_\te{in}$. It is thus advised to work at the lowest supercap voltage (i.e. \SI{2.8}{V}) by selecting a supercapacitor with a similar operation voltage range.

\begin{figure}[H]
    \centering
    
    \caption{High-voltage LDO efficiency at \SI{2.5}{V} in function of the load current}
    \label{fig:LDO_efficiency}
\end{figure}

\chapter{Sensing subsystem}

Sound waves are generated by the variation of a physical characteristic, the pressure. This deviation propagates via vibrations in the environment in such a way that sound can be measured by a microphone from a distance of the source.

Sound waves are often described in terms of sinusoidal plane waves (see Figure~\ref{fig:sound_wave}). Hence, they have a direction of propagation, a speed $v$, a frequency $f$ and an amplitude $A$. 

\begin{figure}[H]
\centering
\begin{tikzpicture}[x={(-10:1cm)},y={(90:1cm)},z={(210:1cm)}]
    % Axes
    \draw (-1,0,0) node[above] {$x$} -- (5,0,0);
    \draw (0,0,0) -- (0,2,0) node[above] {$y$};
    \draw (0,0,0) -- (0,0,2) node[left] {$z$};
    % Propagation
    \draw[->,ultra thick] (5,0,0) -- node[above] {$v$} (6,0,0);
    % Waves
    \draw[thick] plot[domain=0:4.5,samples=200] (\x,{cos(deg(pi*\x))},0);
    % Arrows
    \foreach \x in {0.1,0.3,...,4.4} {
        \draw[->,help lines] (\x,0,0) -- (\x,{cos(deg(pi*\x))},0);
    }
    % Labels
    \node[above right] at (0,1,0) {$A$};
    \node[below] at (0,0,1) {};
\end{tikzpicture}
\caption{General sound wave description}
\label{fig:sound_wave}
\end{figure}

The amplitude of sound pressure corresponds to the loudness of a sound and is typically expressed as the root mean square (RMS) amplitude, called sound
pressure level (SPL). Let the RMS sound pressure be $p=A/\sqrt{2}$ for sine waves, the SPL amplitude is given by
\[
 L_p = 20\log_{10}\left(\frac{p}{p_0}\right) \simeq 20\log_{10}(p) + 94 \quad [\si{dB_{SPL}}]
\]
where $p_0=\SI{20}{\micro Pa}$ is the reference RMS pressure (hearing threshold of humans at \SI{1}{kHz}).

Additionally, the sound SPL amplitude changes over the distance (from $r_1$ to $r_2$) according to the propagation law of spherical waves:
\[
 L_{p_2} = L_{p_1} + 20\log_{10}\left(\frac{r_2}{r_1}\right) \quad [\si{dB_{SPL}}].
\]

Table~\ref{tab:sound_levels} gives typical sound pressure levels.

\begin{table}[H]
\centering
\scalebox{1}{
\begin{tabular}{lcc}
\toprule
  Source of sound & Distance & Sound pressure [dB] \\ \midrule
  Jet engine           & \SI{1}{m}   & 150 \\
  Trumpet              & \SI{0.5}{m} & 120 \\
  Traffic on busy road & \SI{10}{m}  & 90  \\
  Passenger car        & \SI{10}{m}  & 70  \\
  Quiet room           & ambient     & 25  \\ \bottomrule
\end{tabular}
}
\caption{Typical sound pressure levels}
\label{tab:sound_levels}
\end{table}

In this work, the sensor is required to detect the song of a bird (around \SI{50}{dB_{SPL}} at \SI{1}{m} of the source) located \SI{50}{m} away. The minimum detected sound pressure is thus
\[
 L_{p_\te{min}} = 50 - 20\log_{10}(50) = \SI{16}{dB_{SPL}}.
\]
Sound production from several bird species have been measured up to \SI{95}{dB_{SPL}} and are generally greater for larger birds~\cite{FHWA}. The sensor thus needs to detect sounds of at least
\[
 L_{p_\te{max}} = 95 - 20\log_{10}(50) = \SI{61}{dB_{SPL}}.
\]

The frequency range of human hearing is often reported to be between 20 and \SI{20000}{Hz}, but the ability to hear higher frequencies decreases with age. For this reason, a correction, called A-weighting, is applied to instrument-measured sound levels to account for the relative loudness perceived by the human ear as a function of the frequency (see Figure~\ref{fig:a_weighting}).

\begin{figure}[H]
    \centering
    \input{img/a_weighting.tex}
    \caption{A-weighting curve}
    \label{fig:a_weighting}
\end{figure}

Many bird songs have frequency ranges between \SI{1}{kHz} and \SI{8}{kHz}, which places them in the spot of human hearing. However, some birds can produce sounds at frequencies\footnote{One might also want to assess the impact of moving birds on the frequency. For this purpose, the Doppler effect characterizes the frequency $f$ perceived at the sensor node compared to the emitted frequency $f_s$ of the bird when it moves at speed $v_s$. The relative variation of frequency is given by $ f/f_0 = \frac{v}{v \pm v_\text{s}}$ where $v$ is the sound velocity (\SI{343}{m/s} in ambient conditions). For a typical bird velocity (\SI{12}{m/s}), the equation provides a relative variation of $\pm \SI{4}{\%}$, which corresponds to a small (but non-negligible) impact on the perceived frequency.} as low as \SI{23}{Hz}~\cite{10.2307/4090277} or as high as \SI{15}{kHz}~\cite{doi:10.1111/j.1474-919X.1962.tb08647.x}. Since the presented sensor aims to mainly analyze bird sounds, it has to match the frequency specifications ranging between \SI{20}{Hz} and \SI{20}{kHz}.

In the end, the characteristics of the sound wave at the sensor are summed up in Table~\ref{tab:wave_charact_sensor}.

\begin{table}[H]
\centering
\scalebox{1}{
\begin{tabular}{lcc}
\toprule
  Pressure range & 16 -- 61 & \si{dB_{SPL}} \\
  Frequency range  & 20 -- 20000 &  Hz      \\ \bottomrule
\end{tabular}
}
\caption{Sound wave characteristics at the sensor}
\label{tab:wave_charact_sensor}
\end{table}

As depicted in Figure~\ref{fig:sensing_subsystem}, the sensing subsystem is composed of a microphone and a signal conditioning circuit called analog front-end. This block handles the signal transmission from the input sound pressure detected by the microphone to an analog voltage $V_{\te{mic,ADC}}$ further processed by a microcontroller.

\begin{figure}[H]
\centering
\begin{tikzpicture}
    \node (afe) [afes] {Analog Front-End};
    \path (afe.0)+(-6,0) node (mic) [sensor] {Microphone};
    \path [draw, ->] (mic) -- node [above] {$I_{\te{mic,AC}}$} (afe.west |- mic) ;
    \draw [->] (afe.0) -- node [ann] {} + (1,0) node[right] {$V_{\te{mic,ADC}}$};
\end{tikzpicture}
\caption{Block diagram of the sensing subsystem}
\label{fig:sensing_subsystem}
\end{figure}

\section{Microphone}

A microphone is a device that converts sound into an electrical signal (also called transducer). Generally, they mimic the inner workings of human ear by using a diaphragm which vibrates with the sound pressure. There exist several types of microphones for which the most important characteristics, called figures of merit, need to be compared.

\subsection*{Main types of microphone}

Microphones are categorized by their transducer principle, corresponding to the way they detect the variation of input sound pressure.

\subsubsection*{Carbon microphones}

Carbon microphones were the first created type of electrical microphone. They are based on the variation of electrical resistance between two plates due to the motion of a diaphragm on one of these plates. This type of microphone is less used because of its limited frequency response and high noise level (background and crackling noise~\cite{background.noise}).

\subsubsection*{Optical microphones}

Optical microphones use the moving diaphragm as a reflection plate for the light of a laser. The intensity of the light, depending on the deformation of the diaphragm, is converted to an electrical signal through a photodiode. Their high power consumption (more than \SI{5}{mW}, \SI{5.4}{mW} in~\cite{optical_microphone})  prevents them from being used in IoT applications.

\subsubsection*{Condenser microphones}

Condenser microphones are based on a parallel-plate capacitor for which one of the plates is the diagram. For a fixed charge $Q$ on the capacitor, the voltage across the capacitor varies with the capacitance according to
\[
V = \frac{Qd}{\varepsilon A}
\]
where $s$ is the distance between the plates, $A$ is the area of the plate, and $\varepsilon$ is the electric permittivity of the medium inside the plates.

This type can be further divided in active and passive condenser microphones.

Active condenser microphones require biasing circuitry to charge the capacitor and perform first stage amplification. In this group belong microelectromechanical systems (MEMS) microphones which are small package condenser microphones made using semiconductor production techniques. Typically, they already integrate an ADC inside. The small size and the rather low power consumption (\SI{10}{\micro W} to  \SI{1}{mW}~\cite{ICS40720},~\cite{10.3390/mi9070323}) of MEMS microphones are ideal for IoT applications.
 
Passive condenser microphones do not require biasing of the capacitor. For instance, condenser electret microphones have an electret material as diaphragm, a material that has a permanent electrical charge on it. Passive microphones are also appealing for their low power consumption and reduced complexity.
 
\subsubsection*{Piezoelectric microphones}

Piezoelectric microphones directly translate the sound pressure into a voltage by means of a piezoelectric crystal, which redistributes the charges in the crystal under a deformation. They can be packaged in MEMS microphones and have a low power consumption (about \SI{300}{\micro W}~\cite{PMM-3738-VM1000-R}). However, their high impedance makes them sensitive to electrostatic pick-up of hum\footnote{Mains hum is a sound associated with alternating current at the frequency of the mains electricity (\SI{50}{Hz}).}, which decreases its performance in the presence of mains-powered audio equipment or AC electromagnetic fields from nearby appliances.

\subsubsection*{Inductive microphones}

Inductive microphones are passive microphones working via electromagnetic induction. The vibrations of the diaphragm move a permanent magnet through a coil, inducing an electrical current. They are generally less sensitive, especially at picking up high frequencies and short, detailed sounds. They are also unable to pick up distant sounds laterally and from the back of the microphone, which may lead to flatter audio (unidirectionality). They are thus not suited for this application.

\subsection*{Figures of merit}

In order to select the most suited type of microphone for this application, one has to characterize the main figures of merit related to a microphone.

\subsubsection*{Power consumption}

For both active and passive microphones, the operation current and voltage are of essential importance in IoT applications. The standard operation voltage $V_{\te{mic}}$ (also called bias voltage) is the voltage needed by the microphone to operate with full functionality, so that the microphone can amplify and record signals fully. The maximum current consumption is often specified to provide a rough upper limit. However, one is more interested in the measurement of the microphone IV curve which allows deducing the operation current $I_{\te{mic}}$ at the operation voltage.

\subsubsection*{Sensitivity}

Sensitivity is the electrical response at the microphone output to a given standard acoustic input. The standard reference input signal for microphone sensitivity measurements is a \SI{1}{kHz} sine wave at \SI{94}{dB_{SPL}}, or \SI{1}{Pa}. It is expressed in \si{V/Pa} or in \si{dB}.

\subsubsection*{Signal-to-noise ratio}

In the microphone's framework, the signal-to-noise ratio (SNR) specifies the ratio of a reference signal to the noise level of the microphone output. Brought back to the input, the SNR is the difference in decibels between a standard \SI{1}{kHz}, \SI{94}{dB_{SPL}} reference signal and the microphone pressure noise\footnote{The microphone SNR is independent from the input sound pressure. It should not be confused with the typical definition of the SNR, which provides the power ratio between the input signal and the noise at a specific stage of a conditioning chain.}. It is an image of the noise generated inside the microphone, called self-noise. Expressed in \si{dB_{SPL}}, the self-noise acts like a theoretical external noise source placed at the input of an ideal microphone. The relation between the self-noise and the SNR is thus given by
\[
 \te{SNR} = 94 - \te{self-noise} \quad \si{[dB]}.
\]
The SNR is calculated by measuring the noise output of the microphone in a quiet, anechoic environment. This specification is typically presented over a \SI{20}{kHz} bandwidth as an A-weighted value.

\subsubsection*{Frequency response}

The frequency response describes the output level across the frequency spectrum. The high and low frequency limits are described as the points at which the microphone response is \SI{3}{dB} below the reference output level at \SI{1}{kHz}, which is customarily normalized to \SI{0}{dB}. As for the SNR, the frequency response characterization requires precise measurements in anechoic chamber. Typical microphone frequencies lie in the human hearing range.

\iffalse
\subsubsection*{Output impedance}

The output impedance is a measurement of the AC resistance (at \SI{1}{kHz}) looking back into the microphone.
\fi

\subsubsection*{Directionality}

Directionality describes the pattern in which the microphone sensitivity changes when the sound source changes position in space. Most of the analyzed microphones are omnidirectional.

Finally, the main figures of merit associated with a microphone are summarized below:

\begin{itemize}
 \item $I_{\te{mic}}$: rated current (in A),
 \item $V_{\te{mic}}$: rated voltage (in V),
 \item $S$: sensitivity from the input sound pressure to the output voltage (in dB),
 \item $\te{SNR}_{\te{mic}}$: signal-to-noise ratio (in dB),
% \item $R_\te{L}$: output impedance (in [\si{\ohm}]),
 \item the frequency range (in Hz),
 \item the directionality,
 \item and the operating temperature (in \si{\degree C}).
\end{itemize}

\subsection*{Microphone type selection}

IoT devices are limited by their size, cost and energy requirements. Table~\ref{tab:mic_types_comparison} quantitatively summarizes the two main characteristics for each type of microphone.

\begin{table}[H]
\centering
\scalebox{0.98}{
\begin{tabular}{lccc}
\toprule
  Type                 & Reference      & Noise [\si{dB_{SPL}}] & Power cons. [\si{\micro W}]             \\ \midrule
  Condenser (MEMS)     & ICS-40720  & 24 & 570     \\
  Condenser (Electret) & AOM-5024L-HD-R & 14 & 420     \\
  Piezoelectric        & PMM-3738-WP-R  & 33 & 300     \\ \bottomrule
\end{tabular}
}
\caption{Comparison of several types of microphone}
\label{tab:mic_types_comparison}
\end{table}

A piezoelectric microphone is not considered due to its sensitivity to electrostatic pick-up of hum. MEMS and electret condenser microphones are very similar and well suited for this application, but MEMS microphones already have the amplification circuit inside.
Finally, an electret condenser microphone is selected for this work since it allows a precise design of the amplification circuit, optimizing the whole noise and power consumption.

\subsection*{Electret condenser microphone selection}

Considering the main figures of merit stated above, Table~\ref{tab:mic_comparison} compares several state-of-the-art electret condenser microphones.

The AOM-5024L-HD-R microphone has been selected since it surpasses the others in terms of the most important parameters, the self-noise (related to the SNR) and the sensitivity, while roughly keeping the same power consumption. With its self-noise of \SI{14}{dB_{SPL}}, it is in fact the only microphone that allows staying below the \SI{16}{dB_{SPL}} limit for the minimum detectable sound wave.

\begin{table}[H]
\centering
\scalebox{0.95}{
\begin{tabular}{lccc}
\toprule
                              & ABM-707-RC  & CMC-6027-24L100 & AOM-5024L-HD-R \\ \midrule
 Current [\si{\micro}A]       & 500         & 500             & 500            \\
 Voltage [V]                  & 1.5         & 2               & 2              \\
 Sensitivity [dB]             & -41         & -24             & -24            \\
 SNR [dB]                     & 60          & 70              & 80             \\
 Output impedance [\si{\ohm}] & 2.2         & 2.2             & 2.2            \\
 Frequency range [Hz]         & 50 -- 16000 & 100 -- 20000    & 20 -- 20000    \\
 Temperature [\textdegree C]  & -20 -- 60   & -20 -- 70       & -30 -- 70      \\ \bottomrule
\end{tabular}
}
\caption{Comparison of several electret condenser microphones}
\label{tab:mic_comparison}
\end{table}

However, one has to characterize more precisely the current and voltage characteristics because the values given in the datasheets are very general (current of \SI{500}{\micro A} and voltage of \SI{2}{V}). The IV curve of the AOM-5024L-HD-R and the ABM-707-RC\footnote{The ABM-707-RC, which was initially available in the laboratory, served as a first measurement to characterize the microphone and the analog front-end.} is given in Figure~\ref{fig:IV_mic}.

\begin{figure}[H]
    \centering
    \input{img/IV_mic.tex}
    \caption{IV curve of several microphones}
    \label{fig:IV_mic}
\end{figure}

%\textcolor{green}{Retest SMU with less noise (adapt correct range of measurement) -> K2400}

%\textcolor{green}{For AOM-5024L: test variation of audio sensitivity with the operating voltage (relative compared to 2 V) with a fixed sound source: possible to bias below 2 V ? -> mydaq}

In order to select the best operating voltage, one has to find a trade-off between keeping a low voltage (and thus a low power consumption) and having a sufficient sensitivity by retaining the microphone transistor in saturation. Finally, the operating point given in Table~\ref{tab:op_point_mic} for the AOM-5024L-HD-R will be considered in the following. One can sadly notice a power consumption slightly higher than the reference microphone, this model remains the best suited because of his high precision (the self-noise of the reference microphone is too high to be considered in this work).

\begin{table}[H]
\centering
\begin{tabular}{lcc}
\toprule
 Current & $I_{\te{mic}}$   & \SI{358}{\micro A} \\
 Voltage & $V_{\te{mic}}$   & \SI{2}{V}          \\ \bottomrule
\end{tabular}
\caption{Operating point of the AOM-5024L-HD-R microphone}
\label{tab:op_point_mic}
\end{table}

\section{Analog front-end}
\label{section:AFE}

Once the microphone type is selected, one can analyze in more detail the working principle of electret microphones.
The voltage variation across the electret capacitor varies with the capacitance, acting as an AC-coupled voltage source. Because the charge on the microphone capacitor must be fixed, the amplifier circuitry directly in contact with it must have extremely high input impedance, such that no charge can flow through the amplifier circuit. 

For this reason, most electret microphones have an internal junction field-effect transistor (JFET) which buffers the microphone capacitor. The voltage signal produced by sound modulates the gate voltage of the JFET ($V_\te{G}$), causing a change in the current flowing between the drain and source of the JFET ($I_{\te{mic}}$). An extremely high resistance may be included to bias the gate of the JFET, but parasitic resistance in the microphone PCB will be sufficient in this work.

\begin{figure}[H]
\centering
\begin{circuitikz}[scale=0.5]
    \draw (3.5,-4) node[op amp, scale = 0.5](opamp){} 
        (opamp.+) node[left] {}
        (opamp.-) node[left] {}
        (opamp.out) node[right] {}
        (opamp.down) node[ground] {}
        (opamp.up) ++ (0,.5) node[above] {$V_\te{CC}$}
        -- (opamp.up);
    \draw (3.5,4.5) --  (1.0,4.5) -- (1.0,1.5); % wire w3_w5 polyline 
    \draw (3.5,1.5)-- (1.0,1.5);% wire w6
    \draw (8.5,1.5)-- (6.0,1.5);% wire w8
    \draw (8.5,1.5) --  (8.5,4.5) -- (5.5,4.5); % wire w4_w7 polyline 
    \draw (-7.0,1.5)-- (-7.0,2.0);% wire w9
    \draw (-7.0,-3.5)-- (-7.0,-2.0);% wire w11
    \draw (-8.5,-6.0)-- (-8.5,-6.0);% wire w21_w22 end
    \draw (-7.0,-3.5) to [red,short,i_=$I_{\te{mic}}$] (-7,-5) to[Tnjfet,n=jfet,mirror] (-7.0,-13.0);
    \node (A) at (-10,1) {};
    \draw (jfet.G) -- (A |- jfet.G) to[C] (-10,-13) -- (-7,-13);
    \draw (-3.5,-3.5)to[red,short, i=$I_\te{AC}$] (-7.0,-3.5);% wire w12
    \draw (1.0,-3.5)-- (1.0,1.5);% wire w13
    \draw (1.0,-3.5)-- (-1.5,-3.5);% wire w14
    \draw (opamp.-)-- (1.0,-3.5);% wire w15
    \draw (8.5,-4.0)-- (8.5,1.5);% wire w16
    \draw (8.5,-4.0)-- (opamp.out);% wire w17
    \draw (10.0,-4.0)-- (8.5,-4.0);% wire w18
    \draw (2.5,-4.5)-- (2.5,-4.5);% wire w19_w29 start
    \draw (1.5,-10.5)-- (1.5,-10.5);% wire w19_w29 end
    \draw (opamp.+) --  (1.5,-4.5) -- (1.5,-10.5); % wire w19_w29 polyline
    \draw (-3.0,-7.5)-- (-3.0,-7.0);% wire w24
    \draw (-8.5,-7.5)-- (-8.5,-7.5);% wire w23_w25 end
    \draw (-3.0,-10.5)-- (-3.0,-10.0);% wire w28
    \draw (1.5,-10.5)-- (-3.0,-10.5);% wire w30
    \draw (-3.0,-11.0)-- (-3.0,-10.5);% wire w31
    \draw (1.5,-11.5)-- (1.5,-10.5);% wire w32
    \draw (-3.0,-14.5)-- (-3.0,-13.5);% wire w33
    \draw (1.5,-13.5) --  (1.5,-14.5) -- (-3.0,-14.5); % wire w34_w35 polyline 
    \draw (-3.0,-15.0)-- (-3.0,-14.5);% wire w36
    \draw (-3.0, -15.0) node[ground, xscale=1, yscale=1, rotate=0, ] (undefined) {};%  (undefined)++(0.0,0.0) node {undefined }; % component "circuiTikz\\gnd" "undefined" 
    \draw (-7.0, -13.0) node[ground, xscale=1, yscale=1, rotate=0, ] (undefined) {};%  (undefined)++(0.0,0.0) node {undefined }; % component "circuiTikz\\gnd" "undefined" 
    \draw (-7.0, 1.5) to[R, l=$R_1$] (-7.0,-1.5){} to[red,short,i=$I_{DC}$] (-7.0,-2.0); %\node [] at (-7.5,1.0) {x}; % component "res" "R1" 
    \draw (-3.5, -3.5) to[C, l=$C_1$] (-1.5,-3.5){}; % component "cap" "C1" 
    %\node [] at (-1.5,-3.0) {x}; % component "cap" "C1" 
    \draw (5.5, 4.5) to[C, l=$C_2$] (3.5,4.5){}; % component "cap" "C2" 
    %\node [] at (5.5,5.0) {x}; % component "cap" "C2" 
    \draw (6.0, 1.5) to[R, l=$R_2$] (3.5,1.5){}; %\node [] at (6.5,2.0) {x}; % component "res" "R2" 
    \draw (-3.0, -7.5) to[R, l=$R_3$] (-3.0,-10.0){}; %\node [] at (-3.5,-7.0) {x}; % component "res" "R3" 
    \draw (-3.0, -11.0) to[R, l=$R_4$] (-3.0,-13.5){}; %\node [] at (-3.5,-10.5) {x}; % component "res" "R4" 
    \draw (1.5, -13.5) to[C, l=$C_3$] (1.5,-11.5){}; % component "cap" "C3" 
    %\node [] at (2.0,-13.5) {x}; % component "cap" "C3" 
    \node (VCC) [] at (-7.0,2+0.5) {$V_\te{CC}$};% label mark % label "" "VCC" lbl37 
    \node (Vb) [right] at (1.5,-10) {$V_\te{B}$};
    \node (VCC) [] at (-3.0,-7.0+0.5) {$V_\te{CC}$};% label mark % label "" "VCC" lbl40 
    \node (Vout) [] at (11.0+1,-4.0) {$V_{\te{mic,ADC}}$};
    \node (Vout) [] at (-11.0,-9.0) {$V_\te{G}$};
    \node (lbl88) [lttotitextcolor, align=left] at (-11,-8) {Electret microphone\\ model};% text mark % text "" "Electret microphone model lbl88 " 
    \draw [lttotitextcolor, line width=0.4pt, dashed] (-15.0,-14.5) rectangle (-6.0,-7.0); % sch Rect % schLine "SchRect" (-736, 368)->(-160, 128) style=1
\end{circuitikz}
\caption{Microphone and analog front-end circuit}
\label{fig:circuit_AFE}
\end{figure}

The amplification circuit presented in Figure~\ref{fig:circuit_AFE} is typical for condenser electret microphones~\cite{tidu765}. It allows converting the microphone current $I_\te{AC}$ into an output voltage $V_{\te{mic,ADC}}$ which sweeps the input of a further ADC.

The current in the microphone $I_\te{mic}$ has a DC component ($I_\te{DC}$, characterized in the previous section) necessary to put the internal JFET in the saturation region, and an
AC component ($I_\te{AC}$) caused by sound waves. If the impedance of capacitor $C_1$ is much less than $R_1$ at audio frequencies, then $I_\te{AC}$ will flow through $C_1$ and not $R_1$. The op-amp acts as a transimpedance amplifier, and attempts to hold its inverting input at a constant voltage $V_\te{B}$ by varying its output. The resistors and capacitors of the circuit will be further designed such that, in the audio sound frequency band, $C_2$ and $C_3$ are open-circuited, and $C_1$ is short-circuited.
In this case, the output voltage of the op-amp is simply given by
\[
 V_{\te{mic,ADC}} = R_2\, I_\te{AC} + V_\te{B} \quad \si{[V]}
\]
in this frequency band (see Appendix~\ref{appendix:transimpedance} for details).

Because capacitor $C_1$ is chosen to have a very low impedance at audio frequencies, the voltage at the drain of the microphone JFET ($V_\te{DS}$) varies very little, potentially reducing distortion caused by channel length modulation in the JFET. This makes the circuit very convenient since the drain current $I_\te{mic}$ only depends on the JFET gate voltage $V_\te{G}$, and not the constant voltage $V_\te{DS}$ (due to the channel length modulation, also called Early effect).

Designing this amplification circuit requires more attention than for the microphone since it induces consequent noise which is mainly due to the operational amplifier. The next computations will introduce a trade-off between the noise reduction and the power consumption of common operational amplifiers.

\subsection*{Amplification circuit design}

The parameters of the AOM-5024L-HD-R microphone selected for this design are summed up in Table~\ref{tab:selected_mic_charac} with the experimental current measurements.

\begin{table}[H]
\centering
\scalebox{0.95}{
\begin{tabular}{lcc}
\toprule
 Op. current      & $I_{\te{mic}}$        & \SI{358}{\micro A}                        \\
 Op. voltage      & $V_{\te{mic}}$        & \SI{2}{V}                                 \\
 Sensitivity      & $S_{\te{mic,dB}}$     & \SI{-24}{dB}                              \\
 SNR              & $\te{SNR}_{\te{mic}}$ & \SI{80}{dB}                               \\
 Impedance        & $R_{\te{L}}$      & \SI{2.2}{k\ohm}                           \\
 Frequency range  &                       & \SI{20}{Hz} -- \SI{20}{kHz}               \\
 Temperature      &                       & \SI{-30}{\degree C} -- \SI{70}{\degree C} \\
 \bottomrule
\end{tabular}
}
\caption{Characteristics of the selected microphone: AOM-5024L-HD-R}
\label{tab:selected_mic_charac}
\end{table}

The microphone self-noise is given by $p_{\te{SN,dB}} = \SI{14}{dB_{SPL}}$ and $ p_{\te{SN}} = \SI{100}{\micro Pa}$. Since the microphone outputs a current (and not a voltage) depending on the input pressure, a load impedance $R_{\te{L}}$ has been used to convert the current sensitivity towards the voltage sensitivity.

\subsubsection*{Gain calculation}

First, the dB value of the sensitivity must be converted to a linear value, which is
\[
 S_{\te{V,mic}} = 10^{S_{\te{mic,dB}}/20} = \SI{63.1}{mV/Pa}
\]
expressed in volts per Pascal of air pressure.

Because the preamplifier is a transimpedance type, this must be converted to a value of current per Pascal of air pressure. It can be converted thanks to the microphone impedance, which was used to measure the microphone sensitivity. The output current per Pascal of air pressure is
\[
 S_{\te{I,mic}} = \frac{S_{\te{V,mic}}}{R_{\te{L,mic}}} = \SI{28.7}{\micro A/Pa}.
\]
Then, one has to map the minimum detected input sound pressure to the minimum detected output voltage of the amplifier.

The minimum input sound pressure, determined at the beginning of the chapter, is given by
\[
 L_{p,\te{min}} = \SI{16}{dB_{SPL}} \quad \Rightarrow \quad p_\te{min} = p_0 \, 10^{L_{p,\te{min}}/20} = \SI{126}{\micro Pa},
\]
which is expressed in RMS value. It corresponds to a minimum drain current in the microphone of 
\[
 I_{\te{mic,min,RMS}} = S_{\te{I,mic}} \, p_\te{min} = \SI{3.63}{nA}.
\]
The minimal output voltage depends on the ADC resolution of the microcontroller unit. The STM32L072 has a 12-bit resolution and the operating voltage $V_\te{CC}$ is \SI{2.5}{V} (see Section~\ref{section:operating_voltage}). The ADC voltage resolution is thus
\[
 V_{\te{ADC,res}} = \frac{V_\te{CC}}{2^{12}} = \SI{610}{\micro V}.
\]
In order for the input signal to be read with sufficient precision (6 bits) by the ADC, it has to vary higher than $2^6 \,V_{\te{ADC,res}}$. Based on Figure~\ref{fig:ADC_res}, one can deduce the minimum RMS voltage:
\[
 2^6 \, V_{\te{ADC,res}} = 2 \sqrt{2} \, V_\te{ADC,RMS} \quad \Rightarrow \quad V_\te{ADC,RMS} = 2^4 \sqrt{2} \, V_{\te{ADC,res}} = \SI{13.8}{mV}
\]
or $V_{\te{ADC,RMS}} = \SI{-37.2}{dBV}$.

\begin{figure}[H]
\centering
\begin{tikzpicture}[scale=1]
% Axes:
\draw [->] (-3,0) -- (4,0) node [right]  {$t$};
\draw (-3,0.5) -- (3,0.5) ;
\draw[dashed] (-3,1.5) -- (3,1.5) ;
\draw (-3,2.5) -- (3,2.5) ;
\draw[red] (-3,1.5) sin (-2,2.8) cos (-1,1.5) sin (0,0.2) cos (1,1.5) sin (2,2.8) cos (3,1.5);
\draw[<->] (-3.2,0.5) -- (-3.2,2.5);
\node (Vres) [] at (-4.5,1.5) {$2^6 \, V_{\te{ADC,res}}$};
\draw[<->,brown] (2,1.5) -- (2,2.8);
\node (Vadc) [brown] at (2.5,1.1) {$\sqrt{2} \, V_\te{ADC,RMS}$};
\node (Vadc) [red] at (4,2) {$V_\te{ADC}(t)$};
\end{tikzpicture}
\caption{Resolution and RMS values of ADC voltage}
\label{fig:ADC_res}
\end{figure}

Then, one can compute the transimpedance gain, which maps the RMS values of the input current to the output voltage:
\[
 R_2 = \frac{V_\te{ADC,RMS}}{I_{\te{mic,min,RMS}}} = \SI{3.81}{M\ohm}.
\]
The maximum microphone RMS current appears when the ADC voltage is maximum:
\[
 I_{\te{mic,max,RMS}} = \frac{V_\te{CC}/(2\sqrt{2})}{R_2} = \SI{232}{nA},
\]
corresponding to a maximal input sound pressure of
\[
   p_\te{max} = \frac{I_{\te{mic,max,RMS}}}{S_{\te{I,mic}}} = \SI{8.1}{mPa} \quad \Rightarrow \quad L_{p,\te{max}} = 20\log_{10}\left(\frac{p_\te{max}}{p_0}\right) = \SI{52.1}{dB_{SPL}}.
\]
The input spreads from \SI{16}{dB_{SPL}} to \SI{52.1}{dB_{SPL}}, giving a variation of \SI{36.1}{dB}. It is worth noting that, when expressed in dB, the input variation is exactly equal to the 6-bit output variation\footnote{This is the difference between the bit resolution of the ADC (12) and the number of bits used for the minimum detectable signal (6).} since 
\[
 20\log_{10}\left(2^{6}\right) = \SI{36.1}{dB}.
\]
Thereby, there is a trade-off between the number of bits dedicated to the minimum ADC signal (6 bits) and the input pressure range (6 bits) since they sum to the ADC resolution (12 bits). Still, the maximum input sound pressure of \SI{52.1}{dB_{SPL}} suits quite well the requirements of this work, for which a louder sound is rarely produced by birds (about \SI{60}{dB_{SPL}} at the source~\cite{10.1007/s00265-009-0743-4}).

Figure~\ref{fig:mic_scales} depicts the three main variables of the sensing subsystem expressed in dB scale: the input sound pressure $p$, the microphone voltage $V_{\te{mic}}$ and the output voltage $V_\te{ADC}$.
The output ADC voltage has been fixed by the microcontroller specifications.
The minimum input sound pressure, expressed both in \si{dB} and \si{dB_{SPL}}, has then been mapped to the minimum ADC voltage. In turn, it fixed the maximum input sound pressure since the input pressure range has the same length as the output voltage range previously set.

The only remaining degree of freedom for the microphone and amplification circuit lies in the relative position of the scale in between, characterizing the microphone voltage $V_\te{mic}$. This voltage is obtained from the input sound through the microphone sensitivity $S_{\te{mic,dB}}$, and is converted to the ADC voltage through the voltage gain of the amplification circuit:
\[
 G_{V,\te{dB}} = \frac{V_\te{ADC,RMS}}{V_\te{mic,RMS}} = \frac{R_2 \, I_\te{mic,RMS}}{V_\te{mic,RMS}} = \frac{R_2}{R_\te{L}} \quad \si{[dB]}.
\]
Since the input/output relation is given by
\begin{align*}
  p_\te{dB} + S_{\te{mic,dB}} + G_{\te{V,dB}} &= V_\te{ADC,RMS} \quad \si{[dB]},\\
  \SI{16}{dB} - \SI{94}{dB} + S_{\te{mic,dB}} + G_{\te{V,dB}} &= 
  \SI{-37.2}{dB},
\end{align*}
the scale of the microphone voltage needs to be adapted according to
\[
 S_{\te{mic,dB}} + G_{\te{V,dB}} = \SI{40.8}{dB}.
\]
This relation is useful for a parallel optimization of both the microphone and amplification circuit aiming at selecting the best noise/current consumption characteristic. However, the previous microphone selection has fixed the sensitivity at \SI{-24}{dB} and directly leads to a voltage gain of \SI{64.8}{dB}.

Finally, the figure highlights that the self-noise for this microphone (\SI{14}{dB_{SPL}}) is below the minimum input sound pressure. Brought back to the input pressure domain, the AFE noise will also be computed and added to this intrinsic microphone noise.

\begin{figure}[H]
\centering
\begin{tikzpicture}[scale=1]
\def\SPLmin{1.6}
\def\res{3.61}
\def\vmin{3.72}
\def\Sens{2.4}
\draw[dashed, brown] (-4,\SPLmin) -- (4,\SPLmin) ;
\draw[dashed, brown] (-4,\SPLmin+\res) -- (4,\SPLmin+\res) ;
\draw[<->,brown] (-5,\SPLmin) -- (-5,\SPLmin+\res);
\node (Vadc) [brown,align=left] at (-6,\SPLmin+\res/2) {Input\\pressure\\range};
\draw[<->,brown] (5,\SPLmin) -- (5,\SPLmin+\res);
\node (Vadc) [brown,align=left] at (6,\SPLmin+\res/2) {Output\\voltage\\range};
\draw[->](-4,0)--(-4,10)node[font=\small,above]{$p$ [\si{dB_{SPL}}]};
\foreach\y in {10,20,...,90}{
 \draw[](-4,\y/10)--(-4.1,\y/10)node[left,font=\small]{$\y$};
}
\draw[->](-2,0)--(-2,10)node[font=\small,above]{$p$ [\si{dB}]};
\foreach\y in {-90,-80,...,0}{
 \draw[](-2,\y/10+9.4)--(-2.1,\y/10+9.4)node[left,font=\small]{\y};
}
\draw[->](1,0)--(1,13)node[font=\small,above]{$V_\te{mic}$ [\si{dBV}]};
\foreach\y in {-110,-100,...,0}{
 \draw[](1,\y/10+9.4+\Sens)--(0.9,\y/10+9.4+\Sens)node[left,font=\small]{\y};
}
\draw[->](4,0)--(4,10)node[font=\small,above]{$V_\te{ADC}$ [\si{dBV}]};
\foreach\y in {-40,-30,...,40}{
 \draw[](4,\y/10+\SPLmin+\vmin)--(3.9,\y/10+\SPLmin+\vmin)node[left,font=\small]{\y};
}
\draw[dashed, purple] (-2,9.4) -- (-0.5,9.4) ;
\draw[dashed, purple] (-0.5,9.4+\Sens) -- (2.5,9.4+\Sens) ;
\draw[latex-, purple](-0.5,9.4+\Sens)--(-0.5,9.4);
\draw[latex-, purple](2.5,\SPLmin+\vmin)--(2.5,9.4+\Sens);
\draw[dashed, purple] (2.5,\SPLmin+\vmin) -- (3.5,\SPLmin+\vmin) ;
\node (Vadc) [purple,align=left] at (1.8,\SPLmin+\res+3.5) {$G_{\te{V,dB}}$};
\node (Vadc) [purple,align=left] at (-1.5,\SPLmin+\res+6) {$S_{\te{mic,dB}}$};
\draw[->,dashed] (-2,12.0) to [out=70,in=190] (-0.4,13.2) ;
\draw[->,dashed] (2.2,13.2) to [out=-20,in=100] (3.7,11.5) ;
\node (Vadc) [] at (-2,13.5) {Microphone};
\node (Vadc) [align=left] at (4.5,13.5) {Amplification\\circuit};
\node (Vadc) [teal,align=left] at (-6,1.2) {Microphone\\self-noise};
\draw[dashed, teal] (-4.8,1.4) -- (-4,1.4) ;
\end{tikzpicture}
\caption{Range of $p$, $V_{\te{mic}}$ and $V_\te{ADC}$ along the dB scale}
\label{fig:mic_scales}
\end{figure}

\iffalse
\[
 V_\te{N,mic,ADC} = 10^{-\te{SNR}/20} \, S_{\te{mic}} \, G_{\te{V}} = \SI{205}{\micro V}
\]
is not much detected since it is less than the ADC resolution.
This microphone output noise voltage is then compared to the ADC voltage resolution, expressed as peak values:
\[
 \te{Microphone Noise Ratio} = \frac{\sqrt{2} \, V_\te{N,mic,ADC}}{V_{\te{ADC,res}}/2} = \SI{79}{\%}.
\]
\fi

The feedback capacitor $C_2$ compensates for parasitic capacitance at the op-amp inverting input which can cause instability. It also forms a high frequency pole with resistor $R_2$ in the response of the amplifier. According to the frequency range specified for the input sound pressure, the frequency of this pole must be $f_\te{H} = \SI{20}{kHz}$. The feedback capacitor value can then be calculated as
\[
 C_2 = \frac{1}{2 \pi \, f_\te{H} \, R_2} = \SI{2.09}{pF}.
\]

\subsubsection*{Microphone bias resistor and coupling capacitor}

The internal JFET of the electret microphone being biased by resistor $R_1$, the value of this resistor can be calculated from the desired supply voltage ($V_\te{CC}$), the microphone operating voltage ($V_\te{mic}$) and the current consumption ($I_\te{mic}$):
\[
 R_1 = \frac{V_\te{CC} - V_\te{mic}}{I_\te{mic}} = \SI{2.38}{k\ohm}.
\]
Resistor $R_1$ and capacitor $C_1$ form a high-pass filter, the corner frequency of this filter must be low enough not to attenuate low-frequency sound waves. As specified in the input frequency range, a corner frequency of $f_\te{L} = \SI{20}{Hz}$ is used to calculate the value of $C_1$:
\[
 C_1 = \frac{1}{2 \pi \, f_\te{L} \, R_1} = \SI{3.34}{\micro F}.
\]
One can see that reducing $R_1$ (for a higher and thus better microphone operating voltage) requires a larger capacitance (implying more space and cost).

\subsubsection*{Operational amplifier}

The required slew rate of the amplifier can be determined by calculating the maximum rate of change at the op-amp output, arising  for a sine wave at $f_\te{max} = \SI{20}{kHz}$ and an amplitude of $V_\te{CC}/2$ which sweeps the full output range. For sine waves, it can be shown\footnote{This is the highest slope of a sine function, appearing when the signal crosses 0.} that the slew rate is computed as
\[
 \te{SR} = 2 \pi f_\te{max} \frac{V_\te{CC}}{2} = \SI{0.188}{V/\micro s}.
\]
As a conservative rule, it is advised to select ten times this slew rate to eliminate any possibility of slew-induced distortion, which is very important in the analysis of audio data. This sets the required slew rate to \SI{1.88}{V/\micro s}.

The op-amp is selected such that it adds negligible noise to the output of the amplification circuit, avoiding the degradation of the data processing. However, such low-noise operational amplifiers consume a lot of power. One thus has to analyze and compare several state-of-the-art op-amps in order to choose the one which suits the best this noise/power consumption trade-off for this application.

The related op-amp parameters that need to be well selected are the current consumption (quiescent current $I_\te{Q}$), the input current noise spectral density $I_\te{N}$ and the input voltage noise spectral density $E_\te{NV}$.

The ADC voltage noise at the output is based on three noise contributions. The first noise is the thermal noise from resistors $R_1$ and $R_2$:
\[
 E_\te{NR} = \sqrt{4 \, k_\te{B} \, T \, (R_1 \parallelsum R_2)} = \SI{6.26}{nV/\sqrt{Hz}}
\]
where $T = \SI{300}{K}$ is the temperature and $k_\te{B} = \SI{1.38e-23}{J/K}$ is the Boltzmann constant.

The second noise contribution is the op-amp input current noise:
\[
 E_\te{NI} = I_\te{N} \, (R_1 \parallelsum R_2) \quad \left[\si{V/\sqrt{Hz}}\right].
\]
The last noise supply is due to the op-amp input voltage noise $E_\te{NV}$.

The output noise spectral density, for non-correlated contributions, of the amplifier circuit is then given by
\[
 E_\te{N,ADC} = A_\te{N} \sqrt{E_\te{NR}^2 + E_\te{NI}^2 + E_\te{NV}^2} \quad \left[\si{V/\sqrt{Hz}}\right]
\]
for which
\[
 A_\te{N} = 1 + \frac{R_2}{R_1} = 1602
\]
is the noise gain of the op-amp (see Appendix~\ref{appendix:noise_gain} for details). Since the signal gain is directly determined by $R_2$, it cannot be changed. On the other hand, a very low supply voltage $V_\te{CC}$ decreases the value of $R_1$, which increases the noise gain of the op-amp. Hence, the noise/power consumption trade-off also appears in the design of $R_1$.

Finally, the RMS output noise voltage can be computed by multiplying the output noise spectral density by the square of the bandwidth of integration (spreading over an A-weighting curve). An A-weighting curve can be approximated using a \SI{13.5}{kHz} noise bandwidth $B_\te{A}$, the RMS output noise voltage is thus (in RMS value)
\[
 V_\te{N,ADC} = \sqrt{B_\te{A}} \, E_\te{N,ADC} \quad [\si{V}].
\]
This noise contribution is then brought back to the input pressure domain, the \textit{input-referred noise} from the AFE is thus given by
\begin{align*}
  p_\te{IRN,AFE} &= \frac{V_\te{N,ADC}}{R_2\,S_{\te{I,mic}}}\\
   &= \frac{\sqrt{B_\te{A}}}{R_2\,S_{\te{I,mic}}} \left(1 + \frac{R_2}{R_1}\right) \sqrt{4 \, k_\te{B} \, T \, (R_1 \parallelsum R_2) + I_\te{N}^2 \, (R_1 \parallelsum R_2)^2 + E_\te{NV}^2} \quad \si{[Pa]}.
\end{align*}
One can directly see that this noise is roughly independent from the gain $R_2$ since $(1+R_2/R_1)/R_2\simeq 1/R_1$ in our design and the contribution from $I_\te{N}$ is typically negligible compared to $E_\te{NV}^2$.

\iffalse
As for the microphone noise, this output noise voltage is compared to the ADC voltage resolution, expressed as peak values:
\[
 \te{Op Amp Noise Ratio} = \frac{\sqrt{2} \, V_\te{N,ADC}}{V_{\te{ADC,res}}/2} \quad [\%].
\]
\fi

Since the total input-referred noise is composed of non-correlated sources (from the microphone $p_{\te{SN}}$ and the AFE $ p_\te{IRN,AFE}$), their noise powers add up to give
\[
 p_\te{IRN} = \sqrt{p_{\te{SN}}^2 + p_\te{IRN,AFE}^2} \quad \si{[Pa]}.
\]

Figure~\ref{fig:output_noise_op_amp} presents this input-referred noise with respect to the current consumption for several operational amplifiers. Clearly, the input-referred noise must not exceed the minimum signal sound pressure of \SI{16}{dB_{SPL}}.

The ultra-low-power LMV551 op-amp has a quiescent current of only \SI{37}{\micro A}, but the input-referred noise of \SI{17.85}{dB_{SPL}} exceeds the minimum detectable input pressure.
In order to keep the noise voltage not much detected from the ADC, the input-referred noise typically needs to be smaller than the minimum input signal (as depicted in Figure~\ref{fig:ADC_res_noise}).

The OPA2834 has an input-referred noise of $p_\te{IRN,OA} = \SI{14.22}{dB_{SPL}}$ while keeping a particularly small current consumption of \SI{170}{\micro A}. One finally selects this op-amp since it has the lowest noise in the group of three op-amps which belong to an acceptable range of quiescent current (from \SI{100}{\micro A} to \SI{200}{\micro A}).

\begin{figure}[H]
    \centering
    \input{img/input_noise.tex}
    \caption{Comparison of input-referred noise and current consumption for several operational amplifiers}
    \label{fig:output_noise_op_amp}
\end{figure}

\begin{figure}[H]
\centering
\begin{tikzpicture}[scale=1]
% Axes:
\draw [->] (-3,0) -- (4,0) node [right]  {$t$};
\draw (-3,0.5) -- (3,0.5) ;
\draw[dashed] (-3,1.5) -- (3,1.5) ;
\draw (-3,2.5) -- (3,2.5) ;
\draw[purple] (-3,1.5) sin (-2.5,1.7) cos (-2,1.5) sin (-1.5,1.3) cos (-1,1.5) sin (-0.5,1.7) cos (0,1.5) sin (0.5,1.3) cos (1,1.5) sin (1.5,1.7) cos (2,1.5) sin (2.5,1.3) cos (3,1.5);
\draw[<->] (-3.2,0.5) -- (-3.2,2.5);
\node (Vres) [align=left] at (-4.5,1.5) {Min range\\of $p_{\te{signal}}$};
\node (Vadc) [purple] at (4,2) {$p_\te{IRN}(t)$};
\end{tikzpicture}
\caption{Voltage noise and resolution at the amplification output}
\label{fig:ADC_res_noise}
\end{figure}

%Summing the noise contributions from the microphone and the operational amplifier leads to a total output voltage of 90\% compared to the ADC resolution. One thus expects a maximum digitized error of 1 consecutive code level introduced by the ADC quantization.

In the end, the OPA2834 op-amp characteristics are given in Table~\ref{tab:selected_op_amp}. The slew rate of \SI{26}{V/\micro s} is well above the limit of \SI{1.88}{V/\micro s}.

\begin{table}[H]
\centering
\scalebox{0.95}{
\begin{tabular}{lccc}
\toprule
 Criteria            & Required    & OPA2834    & Units             \\ \midrule
 Supply voltage      & 2.5         & 2.5 -- 5.4 & V                 \\
 Quiescent current   & < 200       & 170        & \si{\micro A}     \\
 Input voltage noise & < 27        & 12         & \si{nV/\sqrt{Hz}} \\
 Input current noise & N/A         & 0.2        & \si{pA/\sqrt{Hz}} \\
 Slew rate           & > 1.88      & 26         & \si{V/\micro s}   \\
 \bottomrule
\end{tabular}
}
\caption{Characteristics of the selected operational amplifier: OPA2834}
\label{tab:selected_op_amp}
\end{table}

\subsubsection*{AFE noise voltage}

The noise voltage from the AFE can be theoretically computed over an A-weighting curve of bandwidth $B_\te{A} = \SI{13.5}{kHz}$ as
\[
 V_\te{N,ADC,theor} = \sqrt{B_\te{A}} \, E_\te{N,ADC} = \SI{2.52}{mV}
\]
where $E_\te{N,ADC}$ depends on the voltage and current noise of the OPA2834.

As a validation of the amp op selection, Figure~\ref{fig:output_noise_op_amp_freq} describes the noise voltage spectral density at the amplification output. 
This noise is the combination of flicker (or $1/f$) noise and thermal (flat band) noise. Hence, it depends on the frequency and is higher for frequencies below the $1/f$ corner frequency: \SI{150}{Hz} for the voltage noise and \SI{900}{Hz} for the current noise, as given in the op-amp datasheet. Since audio signals contain frequencies that are particularly low, the noise is sadly impinged by flicker noise. For a frequency of \SI{22}{Hz}, the noise reaches \SI{37}{\micro V/\sqrt{Hz}}.

Since the noise contribution from the microphone is not represented in the simulation, this simulated noise can be compared to the theoretical value of the AFE noise (\SI{2.52}{mV}). Due to the frequency dependence, one needs to integrate the noise power spectral density over the whole frequency range in order to obtain the output noise voltage:
\[
 V_\te{N,ADC,simu} = \sqrt{\int_{0}^{\infty} E_\te{N,ADC}(f)^2 \, \te{d}f} = \SI{2.37}{mV}.
\]
As expected, the result is very similar to the theoretical one, hence not impinging the previous conclusions for the choice of the best operational amplifier.

%This small contribution compared to the microphone noise makes the total voltage noise in the order of the ADC resolution (104\%), which still allows a low-noise digitization.

\begin{figure}[H]
    \centering
    \input{img/output_noise_freq.tex}
    \caption{Noise voltage spectral density from AFE at the amplification output (from \textsc{LTspice})}
    \label{fig:output_noise_op_amp_freq}
\end{figure}

\subsubsection*{Total noise voltage}

One can then compute the total noise voltage $V_\te{N,tot,theor}$ at the amplification output, resulting from the microphone noise and the AFE noise:
\[
 V_\te{N,tot,theor} = p_\te{IRN} \, R_2\,S_{\te{I,mic}} = \SI{11.2}{mV}.
\]

\subsubsection*{Op amp bias network}

Resistors $R_3$ and $R_4$ center the op-amp input and output at the midpoint between the power supplies to allow the widest possible output signal swing. Therefore $R_3 = R_4$ for $V_\te{B} = V_\te{CC} / 2$. The value of these resistors needs to be very high in order to limit the power supply current drawn by this voltage divider. However, the non-zero op-amp input bias current prevents the bias voltage $V_\te{B}$ to be exactly at $V_\te{CC} / 2$, and this variation worsens with the resistance of the bias resistors. A reasonable choice consists to set a maximum bias voltage relative variation of 0.5\%:
\[
 \Delta V_\te{B} = \frac{1}{2} \, R_3 \, I_\te{b+} < 0.005 V_\te{B} \quad \Rightarrow \quad R_3 < 0.01 \frac{V_\te{CC}}{2I_\te{b+}} = \SI{179}{k\ohm}
\]
where $I_\te{b+} = \SI{70}{nA}$ for the selected op-amp. A final value of
\[
 R_3 = R_4 = \SI{150}{k\ohm}
\]
is finally chosen, which implies a current in the voltage divider of approximately
\[
 I_\te{B} = \frac{V_\te{CC}}{R_3 + R_4} = \SI{8.33}{\micro A}.
\]
This current is small (less than 5\%) compared to the microphone bias current, and is a good trade-off between the power consumption and the bias voltage stability.

Capacitor $C_3$ is included to filter thermal noise created by the resistors and any noise which may be present on the power supply. The corner frequency of the low-pass filter is formed by $R_3$, $R_4$ and $C_3$. It should be well below the operating frequency range in order to prevent noise from affecting the audio performance of the design. A corner frequency of $f_\te{B} = \SI{5}{Hz}$ is selected:
\[
 C_3 = \frac{1}{2 \pi \, f_\te{B} \, (R_3 \parallelsum R_4)} = \SI{424}{nF}.
\]

\subsubsection*{Summary}

Table~\ref{tab:selected_values_microphone} summarizes the theoretical values for the amplification circuit as well as the values actually put on the experimental device depending on the available components.
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

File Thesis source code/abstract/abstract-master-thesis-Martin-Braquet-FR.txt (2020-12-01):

L'Internet des objets (IoT) va conduire au déploiement de milliards de capteurs intelligents connectés pour diverses applications. Un tel déploiement massif de capteurs intelligents n'est pas respectueux de l'environnement si ces capteurs sont remplacés tous les deux ans en raison de la pression qu'ils exercent sur les ressources naturelles et de l'écotoxicité des déchets électroniques qu'ils génèrent.
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

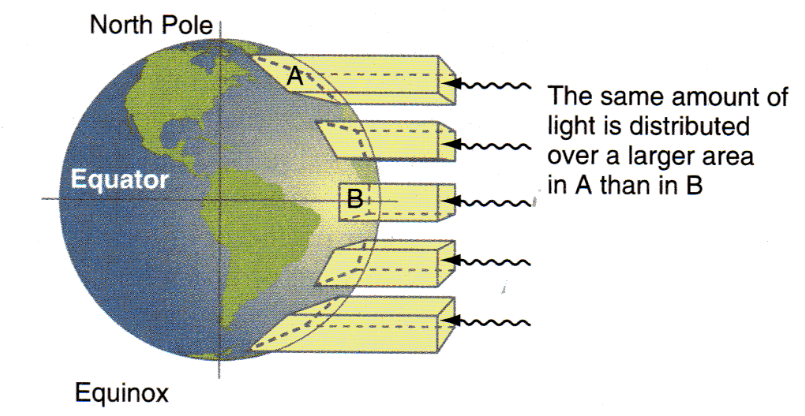
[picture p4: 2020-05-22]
Thesis source code/img/sunlight.png

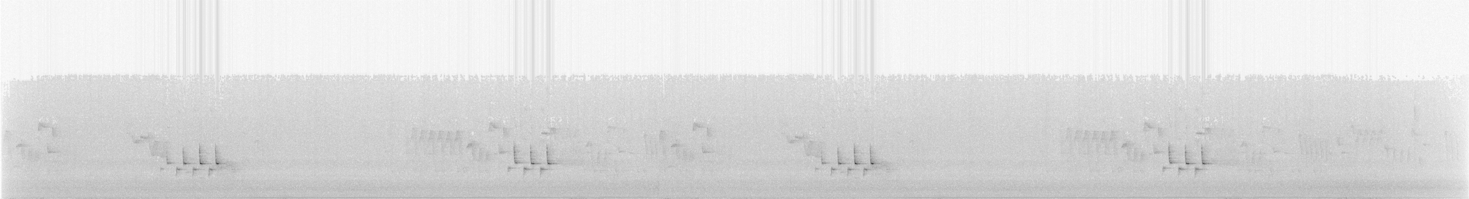
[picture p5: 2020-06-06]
Thesis source code/img/greattit_full-1.png

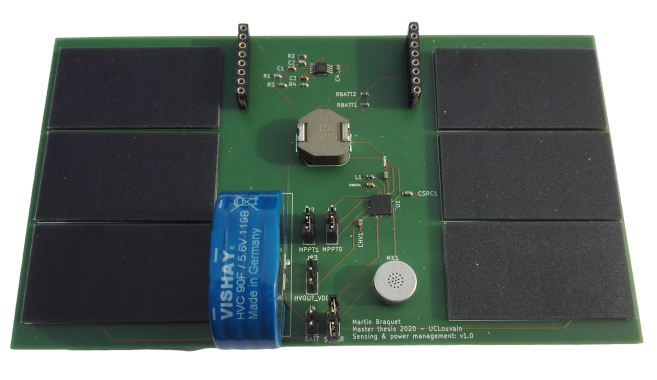
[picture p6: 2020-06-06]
Thesis source code/img/real_PCB.png

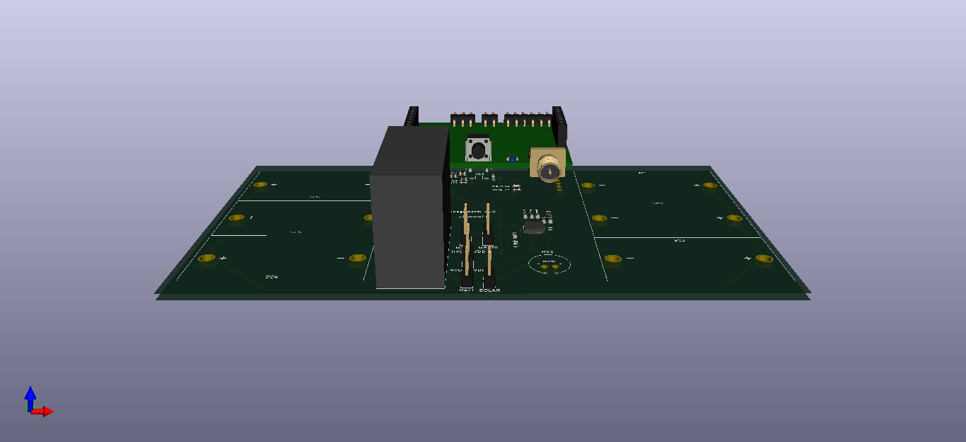
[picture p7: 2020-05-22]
PCB/KiCad/Whole_board.png

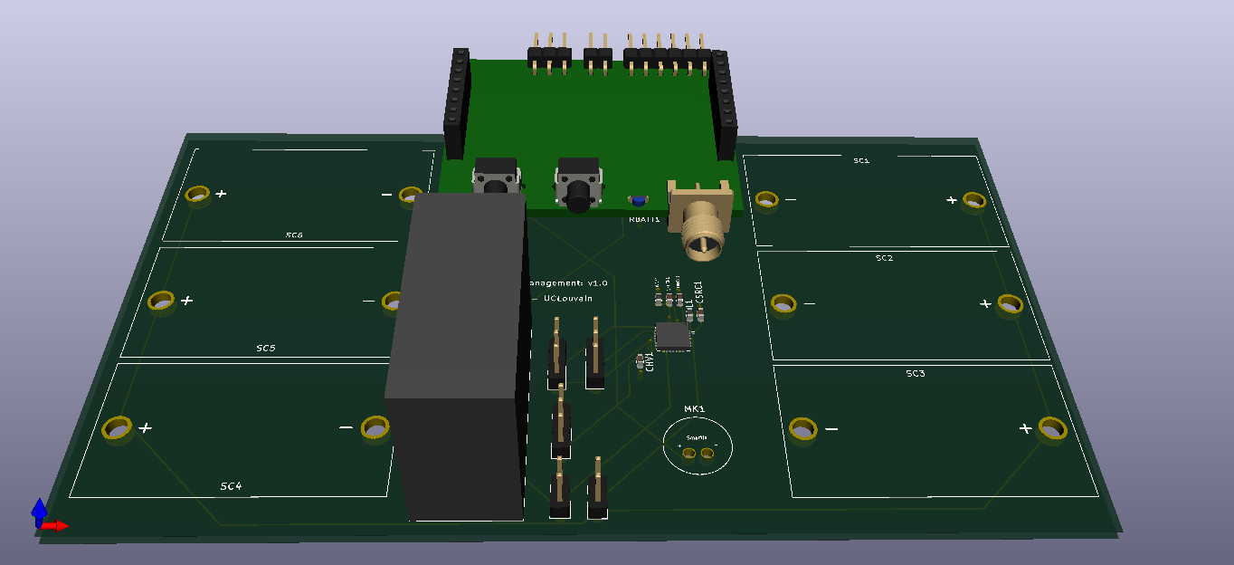
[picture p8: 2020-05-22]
PCB/KiCad/sensing_PMU.png

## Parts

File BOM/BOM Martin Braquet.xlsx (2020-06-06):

COPINE IoT Master thesis
Version 0 | Martin Braquet | 2020-04-08 |  | Number of PCBs | 1
# | Part Reference | Value | Package | Needed quantity per PCB | Needed quantity for X PCBs | Quantity to order | Unit cost [€] | Total cost [€] | Description | Manufacturer Part Number | Manufacturer | Provider | Provider Part Number | Availability | Min quantity to order | Received |  | Cost for 1 piece
1 | C1 | 3,3uF | 0603 | 1 | 1 | 10 | 0.2080 | 2.0800 | CAP CER 3.3UF 16V X5R 0603 | C1608X5R1C335K080AC | TDK | Digikey | 445-7476-1-ND |  | 10 |  |  | 0.208
2 | C2 | 2pF | 0603 | 1 | 1 | 10 | 0.0670 | 0.6700 | CAP CER 2PF 50V C0G/NP0 0603 | GRM1885C1H2R0CA01D | MURATA | Digikey | 490-10713-1-ND |  | 10 |  |  | 0.067
3 | C3 | 470nF | 0603 | 1 | 1 | 10 | 0.1480 | 1.4800 | CAP CER 0.47UF 16V X7R 0603 | GRM188R71C474KA88D | MURATA | Digikey | 490-3295-1-ND |  | 10 |  |  | 0.148
4 | C4 | 100nF | 0603 | 1 | 1 | 10 | 0.0640 | 0.6400 | CAP CER 0.1UF 50V X7R 0603 | 06035C104KAT2A | AVX | Digikey | 478-5052-1-ND |  | 10 |  |  | 0.064
5 | C5 | 90F | 0603 | 1 | 1 | 1 | 17.4500 | 17.4500 | CAP 90F -20% +80% 5.6V T/H | MAL219690102E3 | Vishay BC Components | Digikey | 4707PHBK-ND |  | 1 |  |  | 17.45
6 | CBOOST1 | 22uF | 0603 | 1 | 1 | 10 | 0.1770 | 1.7700 | CAP CER 22UF 6.3V X5R 0603 | GRM188R60J226MEA0D | MURATA | Digikey | 490-7611-1-ND |  | 10 |  |  | 0.177
7 | CHV1, CSRC1, CBUCK1 | 10uF | 0603 | 3 | 3 | 10 | 0.1180 | 1.1800 | CAP CER 10UF 6.3V X5R 0603 | GRM188R60J106KE47D | MURATA | Digikey | 490-12538-1-ND |  | 10 |  |  | 0.354
8 | J3, J4 |  |  | 2 | 2 | 3 | 0.1200 | 0.3600 | CONN HEADER VERT 2POS 2.54MM | 61300211121 | WURTH ELEKTRONIK | Digikey | 732-5315-ND |  | 3 |  |  | 0.24
9 | JP1, JP2, JP3 |  |  | 3 | 3 | 4 | 0.1200 | 0.4800 | CONN HEADER VERT 3POS 2.54MM | 61300311121 | WURTH ELEKTRONIK | Digikey | 732-5316-ND |  | 4 |  |  | 0.36
10 | L1 | 10uH | 0603 | 1 | 1 | 2 | 2.8200 | 5.6400 | FIXED IND 10UH 250MA 1.05 OHM | MLZ1608M100WT000 | TDK | Digikey | 445-6389-1-ND |  | 2 |  |  | 2.82
11 | L2 | 10uH |  | 1 | 1 | 10 | 0.1410 | 1.4100 | FIXED IND 10UH 7.9A 20 MOHM | DFEH12060D-100M=P3 | MURATA | Digikey | 490-13100-1-ND |  | 10 |  |  | 0.141
12 | R1 | 2,37kΩ | 0603 | 1 | 1 | 10 | 0.0200 | 0.2000 | RES 2.37K OHM 1% 1/10W 0603 | RK73H1JTTD2371F | KOA Speer Electronics | Digikey | 2019-RK73H1JTTD2371FCT-ND |  | 10 |  |  | 0.02
13 | R2 | 3,83MΩ | 0603 | 1 | 1 | 10 | 0.0310 | 0.3100 | RES SMD 3.83M OHM 1% 1/10W 0603 | CRCW06033M83FKEA | Vishay Dale | Digikey | 541-3.83MHCT-ND |  | 10 |  |  | 0.031
14 | R3, R4 | 150kΩ | 0603 | 2 | 2 | 10 | 0.0210 | 0.2100 | RES SMD 150K OHM 1% 1/10W 0603 | RC0603FR-07150KL | Yageo | Digikey | 311-150KHRCT-ND |  | 10 |  |  | 0.042
15 | RBATT1, RBATT2 | 475kΩ | 0603 | 2 | 2 | 10 | 0.0150 | 0.1500 | RES 475K OHM 1% 1/10W 0603 | RMCF0603FT475K | Stackpole | Digikey | RMCF0603FT475KCT-ND |  | 10 |  |  | 0.03
16 | SC1, SC2, SC3, SC4, SC5, SC6 |  |  | 6 | 6 | 10 | 5.0670 | 50.6700 | MONOCRYST SOLAR CELL 184MW 4.15V | SM141K06L | IXYS | Digikey | SM141K06L-ND |  | 10 |  |  | 30.402
17 | U2 |  |  | 2 | 2 | 3 | 0.7300 | 2.1900 | CONN HEADER VERT 8POS 2.54MM | 929834-05-08-RK | 3M | Digikey | 3M156870-08-ND |  | 3 |  |  | 1.46
18 |  |  |  | 5 | 5 | 10 | 0.0540 | 0.5400 | CONN JUMPER SHORTING .100" GOLD | QPC02SXGN-RC | Sullins Connector Solutions | Digikey | S9337-ND |  | 10 |  |  | 0.27
 |  | AEM10941 |  | 1 | 1 | 1 | 0.0000 | 0.0000 |  |  |  |  |  |  | 1 |  |  | 0
 |  | TOTAL = |  | 36 | 36 | 144 |  | 87.4300
 |  |  |  |  |  |  |  |  |  |  |  |  |  |  |  |  | PCB | 20
 | Digikey cart: | https://www.digikey.be/short/zp85m5
 |  |  |  |  |  |  |  |  |  |  |  |  |  |  |  |  |  | 74.2840

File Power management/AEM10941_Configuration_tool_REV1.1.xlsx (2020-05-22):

CUSTOM MODE CONFIGURATION (AVAILABLE FOR: AEM10941 - AEM30940)
STEP 1 | Vovdis [V] | 3.3 | Define the overdischarge level for the battery min : 2.2
 | Vchrdy [V] | 3.5 | Define the enable level fo the LDOs min : Vovdis+0.05
 | Vovch [V] | 4.5 | Define the overcharge level for the battery min : Vchrdy+0.05
 | Vhv [V] | 3 | Define the output voltage of the HVOUT max: Vovdis-0.3
STEP 2 | RT [MΩ] | 50.00 | Choose a value between 1MΩ and 100MΩ
 | RV [MΩ] | 35.00 | Choose a value between 1MΩ and 40MΩ
Results | R1 [MΩ] | 11.11 | Fill the blank cells to get the R1 - R6 values
 | R2 [MΩ] | 3.17 |  | RT = | R1+R2+R3+R4
 | R3 [MΩ] | 0.87 |  | RV = | R5+R6
 | R4 [MΩ] | 34.85 |  | RP = | R7+R8
 | R5 [MΩ] | 11.67 |  | RC = | R9+R10
 | R6 [MΩ] | 23.33
PRIMARY BATTERY CONFIGURATION (AVAILABLE FOR: AEM10941 - AEM20940 - AEM30940 - AEM40940)
STEP 1 | VPRIM min [V] | 2 | Define the minimal voltage level on the primary battery min: 0.6 max: 5
STEP 2 | RP [MΩ] | 0.2 | Choose a value between 100kΩ and 500kΩ
Results | R7 [MΩ] | 0.05 | Fill the blank cells to get the R7 - R8 values
 | R8 [MΩ] | 0.15
COLD-START CONFIGURATION (AVAILABLE FOR: AEM10941)
STEP 1 | Vcs [V] | 0.7 | Define the cold-start voltage required min: 0.5 max: 4
STEP 2 | RC [MΩ] | 1 | Choose a value between 100kΩ and 10MΩ
Results | R9 [MΩ] | 0.54 | Fill the blank cells to get the R9 - R10 values
 | R10 [MΩ] | 0.46

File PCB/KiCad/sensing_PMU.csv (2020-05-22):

Id | Designator | Package | Quantity | Designation | Supplier and ref
1 | IC1 | SOP65P490X110-8N | 1 | OPA2834IDGKR
2 | MK1 | AOM-5024L-HD-R | 1 | AOM-5024L-HD-R
3 | SC4,SC6,SC5,SC3,SC2,SC1 | SM141K06L | 6 | SM141K06L
4 | J3 | PinHeader_1x02_P2.54mm_Vertical | 1 | SOLAR
5 | J4 | PinHeader_1x02_P2.54mm_Vertical | 1 | BATT
6 | C5 | MAL219690102E3 | 1 | MAL219690102E3
7 | CBOOST1 | C_0603_1608Metric | 1 | 22u
8 | JP1 | PinHeader_1x03_P2.54mm_Vertical | 1 | MPPT0
9 | JP3 | PinHeader_1x03_P2.54mm_Vertical | 1 | HVOUT_VDD
10 | JP2 | PinHeader_1x03_P2.54mm_Vertical | 1 | MPPT1
11 | J2 | PinSocket_1x08_P2.54mm_Vertical | 1 | Pin2
12 | J1 | PinSocket_1x08_P2.54mm_Vertical | 1 | Pin1
13 | RBATT2,RBATT1 | R_0603_1608Metric | 2 | 100k
14 | R4,R3 | R_0603_1608Metric | 2 | 150k
15 | R2 | R_0603_1608Metric | 1 | 3.83M
16 | R1 | R_0603_1608Metric | 1 | 2.37k
17 | LBUCK1,L1 | L_0603_1608Metric | 2 | 10uH
18 | CSRC1,CHV1,CBUCK1 | C_0603_1608Metric | 3 | 10u
19 | C4 | C_0603_1608Metric | 1 | 100n
20 | C3 | C_0603_1608Metric | 1 | 470n
21 | C2 | C_0603_1608Metric | 1 | 2p
22 | C1 | C_0603_1608Metric | 1 | 3.3u
23 | U1 | QFN28_5X5_05PITCH | 1 | AEM10941

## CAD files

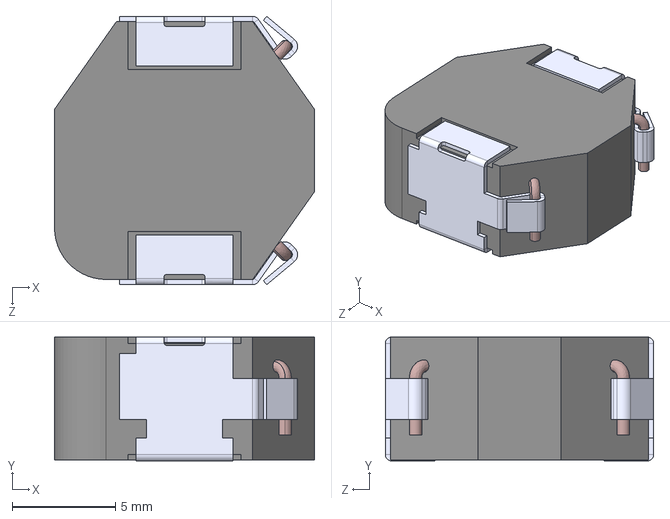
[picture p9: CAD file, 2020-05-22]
PCB/KiCad/DFEH12060D-100M_P3/DFEG12060D-8R2M=P3--3DModel-STEP-46669.STEP
12.6 x 6.00 x 13.0 mm

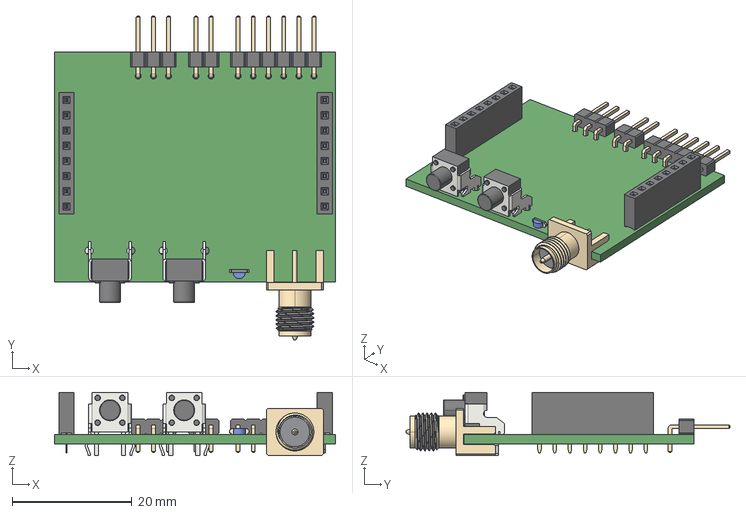
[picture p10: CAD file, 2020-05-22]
PCB/KiCad/Master_Thesis_Tim/Master_Thesis_Tim.step
47.0 x 54.2 x 10.6 mm

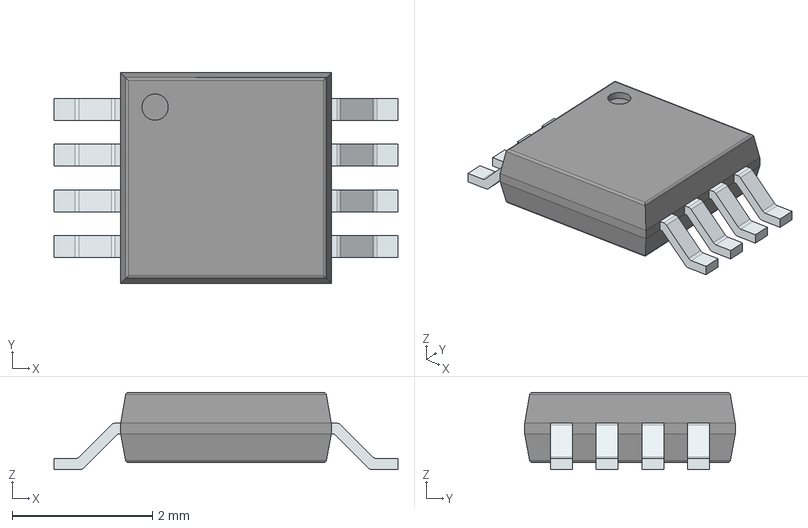
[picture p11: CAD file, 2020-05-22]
PCB/KiCad/OPA2834/OPA2834/OPA2834IDGKR.stp
4.90 x 3.00 x 1.10 mm
PinsArrayLR

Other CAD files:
PCB/KiCad/OPA2834/OPA2834/OPA2834IDGKR.stl

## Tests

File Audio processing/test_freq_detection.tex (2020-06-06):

% This file was created by matlab2tikz.
%
%The latest updates can be retrieved from
%  http://www.mathworks.com/matlabcentral/fileexchange/22022-matlab2tikz-matlab2tikz
%where you can also make suggestions and rate matlab2tikz.
%
\definecolor{mycolor1}{rgb}{0.00000,0.44700,0.74100}%
\definecolor{mycolor2}{rgb}{0.92900,0.69400,0.12500}%
\definecolor{mycolor3}{rgb}{0.46600,0.67400,0.18800}%
\definecolor{mycolor4}{rgb}{0.63500,0.07800,0.18400}%
%
\begin{tikzpicture}

\begin{axis}[%
width=4.521in,
height=3.566in,
at={(0.758in,0.481in)},
scale only axis,
xmin=0,
xmax=7,
xlabel style={font=\color{white!15!black}},
xlabel={Weighted average frequency [kHz]},
ymin=0,
ymax=20,
axis background/.style={fill=white},
axis x line*=bottom,
axis y line*=left,
legend style={at={(0.942,0.098)}, anchor=south west, legend cell align=left, align=left, draw=white!15!black}
]
\addplot [color=mycolor1, draw=none, mark size=2.5pt, mark=*, mark options={solid, mycolor1}]
  table[row sep=crcr]{%
0.901579628386122	0\\
0.598078203756716	0\\
0.875811228066835	0\\
1.25038473443573	0\\
0.98976212228955	0\\
0.603235617097455	0\\
};
\addlegendentry{Pigeon (learning)}

\addplot [color=mycolor1, draw=none, mark size=2.5pt, mark=x, mark options={solid, mycolor1}]
  table[row sep=crcr]{%
0.515	1\\
0.735	1\\
0.515	1\\
};
\addlegendentry{Pigeon (test)}

\addplot [color=mycolor2, draw=none, mark size=2.5pt, mark=*, mark options={solid, mycolor2}]
  table[row sep=crcr]{%
2.78870571216995	0\\
2.9363029875264	0\\
2.60567527145653	0\\
2.01841901994883	0\\
2.07500568984736	0\\
2.75323681757697	0\\
};
\addlegendentry{Blackbird (learning)}

\addplot [color=mycolor2, draw=none, mark size=2.5pt, mark=x, mark options={solid, mycolor2}]
  table[row sep=crcr]{%
1.7	2\\
2	2\\
1.859	2\\
};
\addlegendentry{Blackbird (test)}

\addplot [color=mycolor3, draw=none, mark size=2.5pt, mark=*, mark options={solid, mycolor3}]
  table[row sep=crcr]{%
3.29962072005617	0\\
4.31725108102205	0\\
4.07551437155708	0\\
3.84115723468138	0\\
3.71962555806297	0\\
4.34443207328584	0\\
};
\addlegendentry{Great tit (learning)}

\addplot [color=mycolor3, draw=none, mark size=2.5pt, mark=x, mark options={solid, mycolor3}]
  table[row sep=crcr]{%
4.063	3\\
3.965	3\\
3.52	3\\
};
\addlegendentry{Great tit (test)}

\addplot [color=mycolor4, draw=none, mark size=2.5pt, mark=*, mark options={solid, mycolor4}]
  table[row sep=crcr]{%
5.89537174744149	0\\
5.39086097084435	0\\
4.64672637489751	0\\
5.93736994517614	0\\
5.83043572295634	0\\
6.26599081337915	0\\
};
\addlegendentry{Blue tit (learning)}

\addplot [color=mycolor4, draw=none, mark size=2.5pt, mark=x, mark options={solid, mycolor4}]
  table[row sep=crcr]{%
5.237	4\\
5.741	4\\
5.294	4\\
};
\addlegendentry{Blue tit (test)}

\end{axis}
\end{tikzpicture}%

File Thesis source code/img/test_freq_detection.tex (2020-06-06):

% This file was created by matlab2tikz.
%
%The latest updates can be retrieved from
%  http://www.mathworks.com/matlabcentral/fileexchange/22022-matlab2tikz-matlab2tikz
%where you can also make suggestions and rate matlab2tikz.
%
\definecolor{mycolor1}{rgb}{0.00000,0.44700,0.74100}%
\definecolor{mycolor2}{rgb}{0.92900,0.69400,0.12500}%
\definecolor{mycolor3}{rgb}{0.46600,0.67400,0.18800}%
\definecolor{mycolor4}{rgb}{0.63500,0.07800,0.18400}%
%
\begin{tikzpicture}[scale=0.9]

\begin{axis}[%
width=4.521in,
height=1in,
at={(0.758in,0.481in)},
scale only axis,
xmin=0,
xmax=7,
xlabel style={font=\color{white!15!black}},
xlabel={Weighted average frequency [kHz]},
ymin=0,
ymax=20,
axis background/.style={fill=white},
axis x line*=bottom,
axis y line=none,
legend style={at={(1.142,0)}, anchor= west, legend cell align=left, align=left, draw=none}
]
\addplot [color=mycolor1, draw=none, mark size=2.5pt, mark=*, mark options={solid, mycolor1}]
  table[row sep=crcr]{%
0.901579628386122	0\\
0.598078203756716	0\\
0.875811228066835	0\\
1.25038473443573	0\\
0.98976212228955	0\\
0.603235617097455	0\\
};
\addlegendentry{Pigeon (learning)}

\addplot [color=mycolor1, draw=none, mark size=2.5pt, mark=x, mark options={solid, mycolor1}]
  table[row sep=crcr]{%
0.515	4\\
0.735	4\\
0.535	4\\
};
\addlegendentry{Pigeon (test)}

\addplot [color=mycolor2, draw=none, mark size=2.5pt, mark=*, mark options={solid, mycolor2}]
  table[row sep=crcr]{%
2.78870571216995	0\\
2.9363029875264	0\\
2.60567527145653	0\\
2.01841901994883	0\\
2.07500568984736	0\\
2.75323681757697	0\\
};
\addlegendentry{Blackbird (learning)}

\addplot [color=mycolor2, draw=none, mark size=2.5pt, mark=x, mark options={solid, mycolor2}]
  table[row sep=crcr]{%
1.7	4\\
2	4\\
1.859	4\\
};
\addlegendentry{Blackbird (test)}

\addplot [color=mycolor3, draw=none, mark size=2.5pt, mark=*, mark options={solid, mycolor3}]
  table[row sep=crcr]{%
3.29962072005617	0\\
4.31725108102205	0\\
4.07551437155708	0\\
3.84115723468138	0\\
3.71962555806297	0\\
4.34443207328584	0\\
};
\addlegendentry{Great tit (learning)}

\addplot [color=mycolor3, draw=none, mark size=2.5pt, mark=x, mark options={solid, mycolor3}]
  table[row sep=crcr]{%
4.063	4\\
3.965	4\\
3.52	4\\
};
\addlegendentry{Great tit (test)}

\addplot [color=mycolor4, draw=none, mark size=2.5pt, mark=*, mark options={solid, mycolor4}]
  table[row sep=crcr]{%
5.89537174744149	0\\
5.39086097084435	0\\
4.64672637489751	0\\
5.93736994517614	0\\
5.83043572295634	0\\
6.26599081337915	0\\
};
\addlegendentry{Blue tit (learning)}

\addplot [color=mycolor4, draw=none, mark size=2.5pt, mark=x, mark options={solid, mycolor4}]
  table[row sep=crcr]{%
5.237	4\\
5.741	4\\
5.294	4\\
};
\addlegendentry{Blue tit (test)}

\end{axis}
\end{tikzpicture}%

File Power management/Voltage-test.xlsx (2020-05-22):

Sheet: µC (ADC + FFT)
Voltage [V] |  | 2.397 | 2.499 | 2.601 | 2.703 | 2.805 | 2.907 | 3.009 | 3.111 | 3.213 | 3.315 | 3.417 | 3.485 | 3.587
Average Current consumption [mA] |  | 11.16284528 | 11.25880982 | 11.24834953 | 11.09240658 | 11.19887568 | 11.26308027 | 11.17755528 | 11.08463313 | 11.23610345 | 11.24000664 | 11.27431792 | 11.33441984 | 11.26301089
Average Power consumption [mW] |  | 26.75734014 | 28.13576574 | 29.25695712 | 29.98277499 | 31.41284629 | 32.74177436 | 33.63326385 | 34.48429365 | 36.1016004 | 37.26062203 | 38.52434432 | 39.50045313 | 40.40042006
Average Energy consumption [mJ] |  | 0.5228408345 | 0.5497753947 | 0.5716835753 | 0.5858661218 | 0.6138098436 | 0.6397772177 | 0.6571970026 | 0.6738262016 | 0.7054285209 | 0.7280759079 | 0.7527691552 | 0.7718424093 | 0.789427844
Elapsed time [s] | 0.01954009
 | 0 | 0.01130593113 | 0.01142799622 | 0.01139159554 | 0.01123938265 | 0.01135529908 | 0.01140603671 | 0.01132032763 | 0.01123047975 | 0.0114028805 | 0.01142780268 | 0.01145725075 | 0.01151412216 | 0.01145266531
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

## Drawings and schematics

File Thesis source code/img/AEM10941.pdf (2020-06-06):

# AEM10941

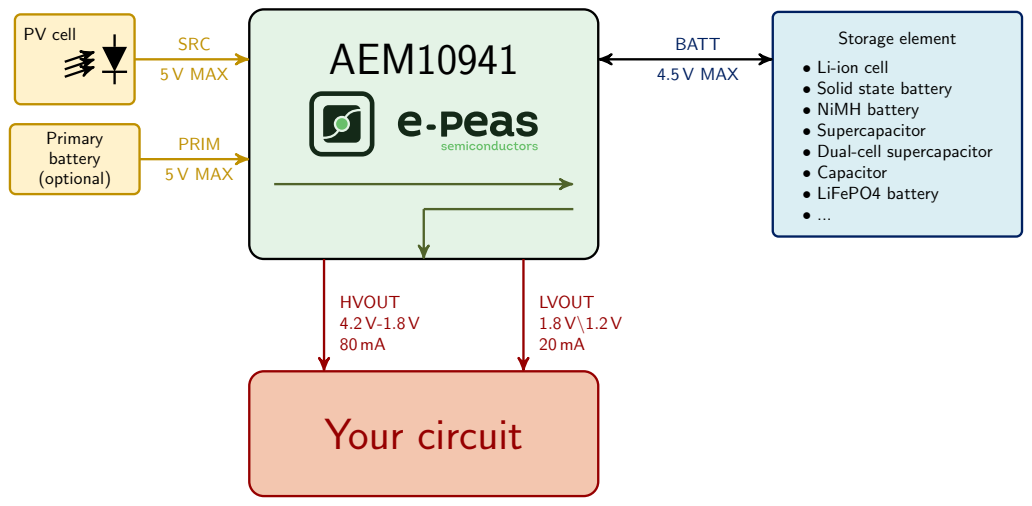
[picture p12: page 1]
PV cell; SRC; 5 V MAX; Primary battery (optional); PRIM; BATT; 4.5 V MAX; Your circuit; HVOUT 4.2 V-1.8 V 80 mA; LVOUT 1.8 V\1.2 V 20 mA

Storage element
• Li-ion cell
• Solid state battery
• NiMH battery
• Supercapacitor
• Dual-cell supercapacitor
• Capacitor
• LiFePO4 battery

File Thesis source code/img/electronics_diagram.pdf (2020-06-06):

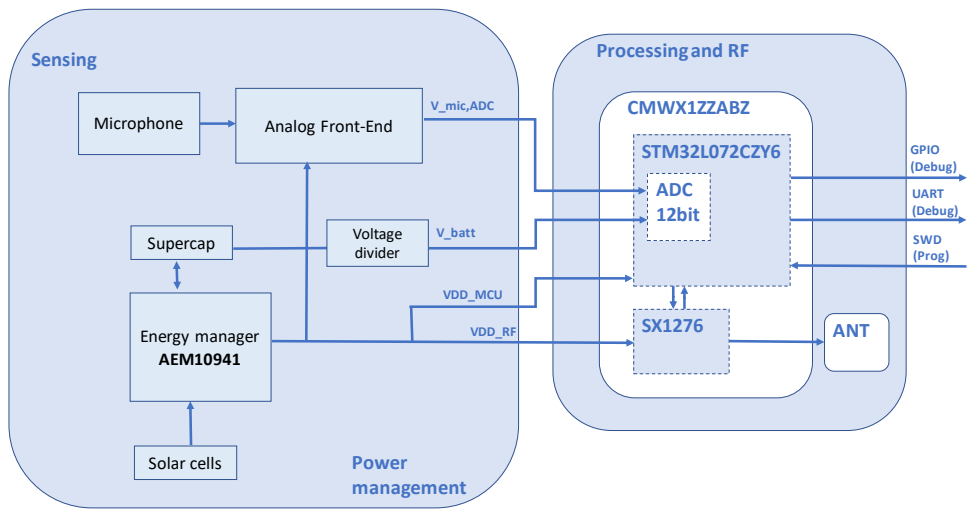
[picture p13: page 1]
Sensing; Power management; CMWX1ZZABZ; STM32L072CZY6; ANT; ADC 12bit; UART (Debug); GPIO (Debug); SWD (Prog); V_mic,ADC; V_batt; VDD_MCU; VDD_RF; Microphone; Analog Front-End; Energy manager AEM10941; Supercap; Solar cells; Voltage divider

Processing and RF

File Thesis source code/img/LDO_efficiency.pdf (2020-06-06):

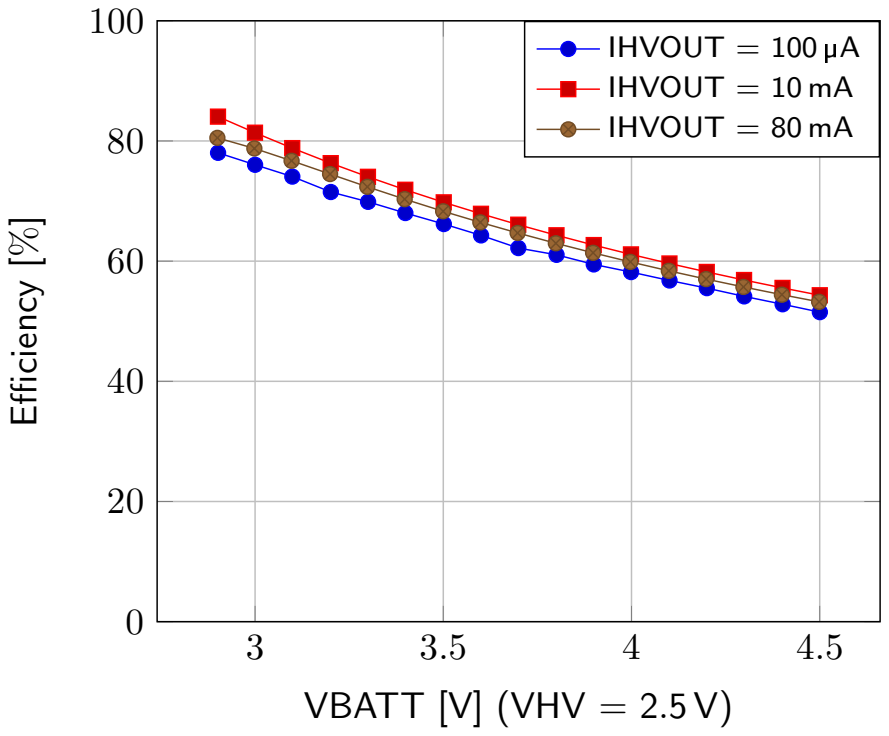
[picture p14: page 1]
VBATT [V] (VHV = 2.5 V); Efficiency [; IHVOUT = 100 µA; IHVOUT = 10 mA IHVOUT = 80 mA

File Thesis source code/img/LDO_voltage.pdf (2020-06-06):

2.6

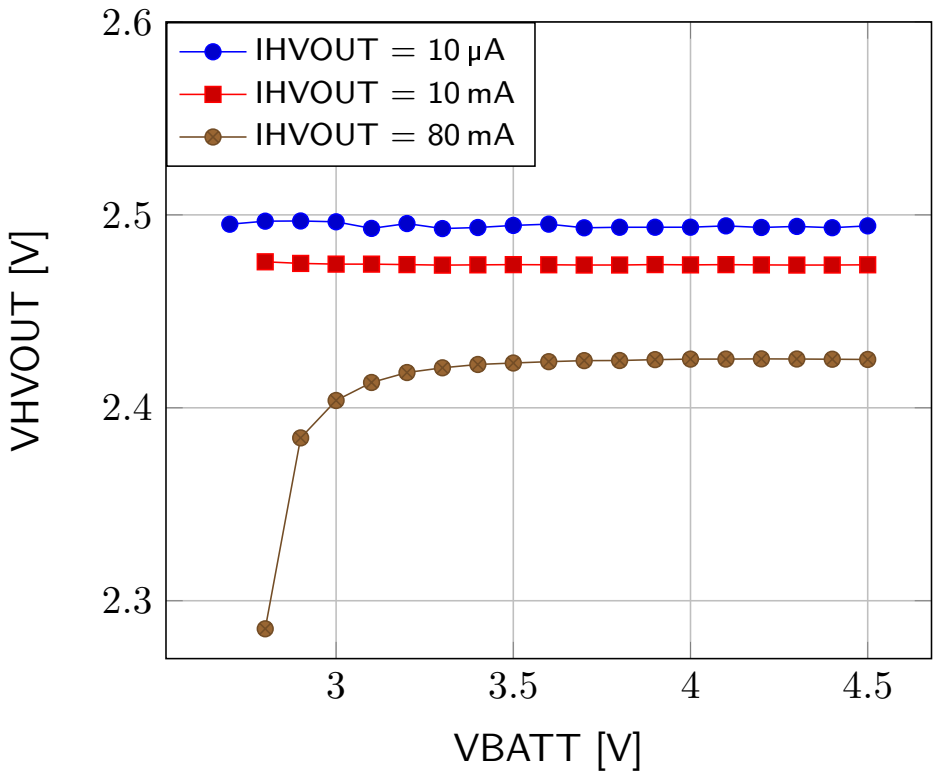
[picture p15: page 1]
VBATT [V]; VHVOUT [V]; IHVOUT = 10 µA; IHVOUT = 10 mA IHVOUT = 80 mA; ILVOUT = 10 µA

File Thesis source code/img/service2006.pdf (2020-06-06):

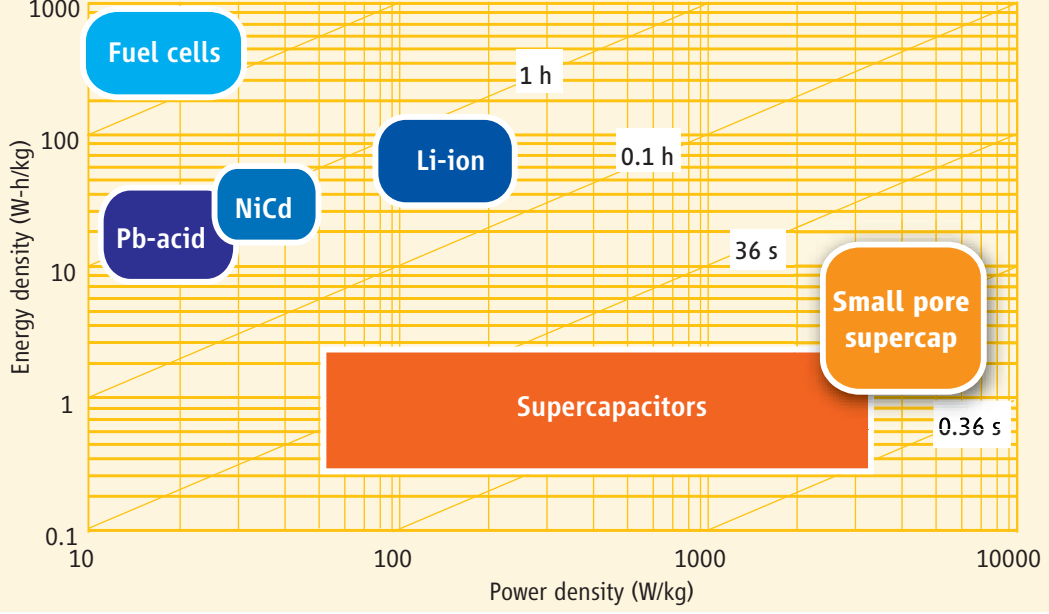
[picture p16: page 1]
Small; pore; supercap; NiCd; Pb-acid

Fuel cells

Energy density (W-h/kg)

Li-ion

Supercapacitors

Power density (W/kg)

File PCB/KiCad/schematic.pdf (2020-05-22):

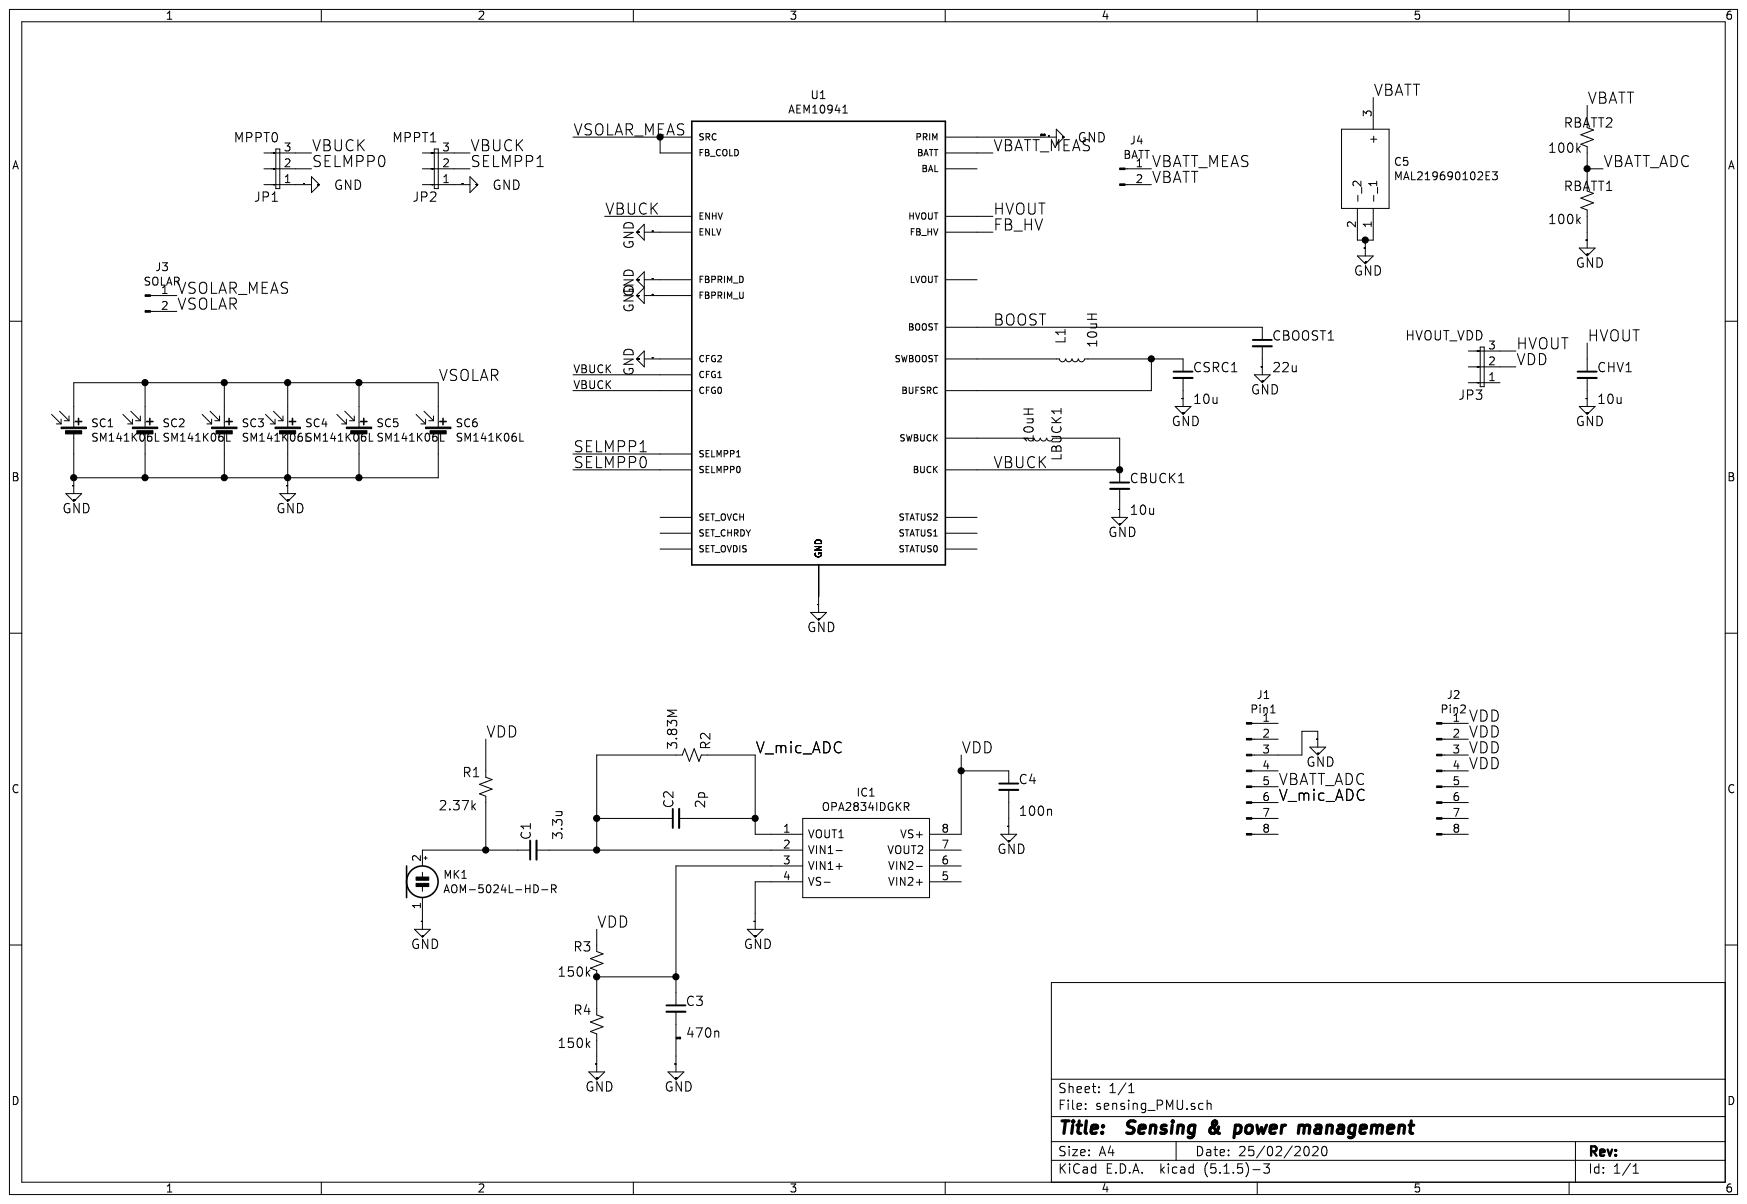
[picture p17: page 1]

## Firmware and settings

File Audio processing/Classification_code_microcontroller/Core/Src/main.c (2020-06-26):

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

#define ARM_MATH_CM0PLUS

/* Includes ------------------------------------------------------------------*/
#include "main.h"

#include "arm_math.h"
#include "arm_const_structs.h"

ADC_HandleTypeDef hadc;

RTC_HandleTypeDef hrtc;

SPI_HandleTypeDef hspi1;

void SystemClock_Config(void);
static void MX_GPIO_Init(void);
static void MX_RTC_Init(void);
static void MX_SPI1_Init(void);
static void MX_ADC_Init(void);
/* USER CODE BEGIN 0 */
void Get_arm_fft(void);
void analyze_sound_temporal(void);
void analyze_sound_temporal_mag(void);
void analyze_sound_spectrogram(void);
void KNN(void);
void MeanFrequency(void);
void print_bird(void);
//static uint32_t GetSector(uint32_t Address);
void store_FLASH();
void read_FLASH();

#define F32
#define RETRIEVE_NB_SONGS_PER_BIRD 0

#define SAMPLE_RATE 30000            // Sample rate of the audio in hertz.
#define SAMPLE_RATE_MAG 30000        // f_s > 30kHz to ensure good processing of frequencies < 8kHz
#define FFT_SIZE 128                    // Size of the FFT.
#define BUNCH_SAMPLE_SIZE 80
#define MAX_INDEX_FREQ FFT_SIZE/2-25
#define DELTA_F SAMPLE_RATE/FFT_SIZE
#define DELTA_F_MAG SAMPLE_RATE_MAG/FFT_SIZE

float samples[FFT_SIZE*2];
float magnitudes[FFT_SIZE];
float mag_spectrogram[MAX_INDEX_FREQ][BUNCH_SAMPLE_SIZE];
float sum_mag_spectrogram[MAX_INDEX_FREQ];
const static arm_cfft_instance_f32 *S;

uint32_t opti_freq;
uint32_t opti_freq_below;
uint32_t opti_freq_table[2*BUNCH_SAMPLE_SIZE];
uint32_t mag_bunch_table[2*BUNCH_SAMPLE_SIZE];
//float32_t opti_freq_amplitude[BUNCH_SAMPLE_SIZE];
uint32_t index_freq[BUNCH_SAMPLE_SIZE];
uint32_t mag_freq[BUNCH_SAMPLE_SIZE];

#define N_BIRDS 4
#define N_SONGS 6
float birds_freq_range[4][6] = {{902, 598, 876, 1250, 990, 603},
		{2788, 2936, 2605, 2018, 2075, 2753},
		{3299, 4317, 4075, 3841, 3719, 4344},
		{5895, 5390, 4646, 5937, 5830, 6266}};
uint32_t temp_freq_range[N_BIRDS][N_SONGS];
float mean_f, temp_delta_freq, sum_mag, min_mag, max_mag;
#define FREQ_MAG_TRESH 300
#define KNN_SIZE 5
uint32_t close_freq_index[KNN_SIZE];
uint32_t KNN_bird_indexes_number[N_BIRDS];
uint32_t bird_index, max_number_songs;
uint8_t no_bird;
float sound_correction[MAX_INDEX_FREQ] = {0, 0, 200, 90, 40, 27, 23, 19, 13, 44, 8, 7, 7, 8, 7, 5, 6, 7, 10, 5, 4, 5, 5, 5, 4, 5, 5, 4, 4, 3, 4, 4, 4, 4, 3, 3, 3, 3, 4};
uint32_t nb_songs_per_bird[N_BIRDS];


uint32_t i, j, k, i_end, j_end, num_sample_bunch, num_freq_table, num_freq_bunch;

uint32_t t_acq, t_getfft, t_runfft, t_magfft, t_bunch,t_fft, t_storage;

float maxValue;            // Max FFT value is stored here
uint32_t maxIndex;         // Index in Output array where max value is

#define FLASH_USER_START_ADDR   ((uint32_t)0x0800A000)   /* Start @ of user Flash area */
uint32_t FirstSector = 0, NbOfSectors = 0;
uint32_t Address = 0, SECTORError = 0;
__IO uint32_t data32 = 0;

extern void initialise_monitor_handles(void);

/* USER CODE END 0 */

/**
 * @brief  The application entry point.
 * @retval int
 */
int main(void)
{
	/* USER CODE BEGIN 1 */
	initialise_monitor_handles();
	/* USER CODE END 1 */

	/* MCU Configuration--------------------------------------------------------*/

	/* Reset of all peripherals, Initializes the Flash interface and the Systick. */
	HAL_Init();

	/* Configure the system clock */
	SystemClock_Config();

	/* Initialize all configured peripherals */
	MX_GPIO_Init();
	MX_RTC_Init();
	MX_SPI1_Init();
	MX_ADC_Init();
	/* USER CODE BEGIN 2 */

	HAL_ADC_Start(&hadc);

#if RETRIEVE_NB_SONGS_PER_BIRD
	read_FLASH();
#endif

	/* USER CODE END 2 */

	/* Infinite loop */
	/* USER CODE BEGIN WHILE */
	while (1)
	{
		/* USER CODE END WHILE */

		/* USER CODE BEGIN 3 */

		//analyze_sound_temporal();
		//analyze_sound_temporal_mag();
		analyze_sound_spectrogram();

		/* USER CODE END 3 */
	}
}

void analyze_sound_temporal(void)
{
	for (i=0; i<2*FFT_SIZE; i+=2) {
		HAL_ADC_PollForConversion(&hadc, 1000);
		samples[i] = HAL_ADC_GetValue(&hadc);
		samples[i+1] = 0;
		//t = HAL_GetTick();
		for (j=0; j<10; j++);
	}

	//t = HAL_GetTick() - t;
	//HAL_Delay(1000);
	//printf("%d\n", HAL_GetTick());
	//HAL_Delay(1000);

	for (i=0; i<2*FFT_SIZE; i+=2) {
		printf("%1.0f ", samples[i]);
	}
	printf("\n");
}

void analyze_sound_temporal_mag(void)
{
	t_bunch = HAL_GetTick();

	for (num_sample_bunch=0; num_sample_bunch<BUNCH_SAMPLE_SIZE; num_sample_bunch++) {
		t_acq = HAL_GetTick();

		for (i=0; i<2*FFT_SIZE; i+=2) {
			HAL_ADC_PollForConversion(&hadc, 1000);
			samples[i] = HAL_ADC_GetValue(&hadc);
			samples[i+1] = 0;
			//t = HAL_GetTick();
			for (int j=0; j<42; j++); // 6.4ms for 128 samples: 20kHz
		}

		t_acq = HAL_GetTick() - t_acq;

		//printf("%d\n", t_acq);

		//t = HAL_GetTick() - t;
		//HAL_Delay(1000);
		//printf("%d\n", HAL_GetTick());
		//HAL_Delay(1000);

		/*
		for (i=0; i<2*FFT_SIZE; i+=2) {
		  printf("%1.0f ", samples[i]);
		}
		printf("\n");
		 */

		t_getfft = HAL_GetTick();
		Get_arm_fft();
		t_getfft = HAL_GetTick() - t_getfft;

		// Run FFT on sample data.
		t_runfft = HAL_GetTick();
		arm_cfft_f32(S, samples, 0, 1);
		t_runfft = HAL_GetTick() - t_runfft;

		// Calculate magnitude of complex numbers output by the FFT.
		t_magfft = HAL_GetTick();
		arm_cmplx_mag_f32(samples, magnitudes, FFT_SIZE);

		for (i=0; i<4; i++) {
			magnitudes[i] = 0;
		}

		arm_max_f32(magnitudes, FFT_SIZE/2, &maxValue, &maxIndex);

		opti_freq = maxIndex * DELTA_F_MAG;

		index_freq[num_sample_bunch] = opti_freq;
		mag_freq[num_sample_bunch] = magnitudes[maxIndex];

		//arm_max_f32(magnitudes, FFT_SIZE/4, &maxValue, &maxIndex);

		//opti_freq_below = maxIndex * 32000 / 355 * 1024 / FFT_SIZE;

		t_magfft = HAL_GetTick() - t_magfft;

		//printf("Optifreq: %d, maxIndex: %d\n", opti_freq, maxIndex);
		//printf("Optifreq below 20kHz: %d, Optifreq: %d, maxIndex: %d\n", opti_freq_below, opti_freq, maxIndex);

		//printf("%d\n ", HAL_GetTick());
	}

	t_bunch = HAL_GetTick() - t_bunch;

	printf("Time: %d  \n", t_bunch);

	printf("\n");
	for (i=0; i<BUNCH_SAMPLE_SIZE; i++) {
		printf("%d ", index_freq[i]);
	}
	printf("\n");
	for (i=0; i<BUNCH_SAMPLE_SIZE; i++) {
		printf("%d ", mag_freq[i]);
	}
	printf("\n");

}

void analyze_sound_spectrogram(void)
{
	t_bunch = HAL_GetTick();

	num_freq_table = 0;

	for (num_sample_bunch=0; num_sample_bunch<BUNCH_SAMPLE_SIZE; num_sample_bunch++) {

		t_acq = HAL_GetTick();

		for (i=0; i<2*FFT_SIZE; i+=2) {
			HAL_ADC_PollForConversion(&hadc, 1000);
			samples[i] = HAL_ADC_GetValue(&hadc);
			samples[i+1] = 0;
			//t = HAL_GetTick();
			for (int j=0; j<48; j++); // j<90 if SAMPLE_RATE = 20000, j<48 if SAMPLE_RATE = 30000
		}

		t_acq = HAL_GetTick() - t_acq;

		//printf("%d\n", t_acq);

		//t = HAL_GetTick() - t;
		//HAL_Delay(1000);
		//printf("%d\n", t_acq());
		//HAL_Delay(1000);
		/*
		  for (int i=0; i<2*FFT_SIZE; i+=2) {
			  printf("%1.0f ", samples[i]);
		  }
		  printf("\n");
		 */

		t_fft = HAL_GetTick();

		t_getfft = HAL_GetTick();
		Get_arm_fft();
		t_getfft = HAL_GetTick() - t_getfft;

		// Run FFT on sample data.
		t_runfft = HAL_GetTick();
		arm_cfft_f32(S, samples, 0, 1);
		t_runfft = HAL_GetTick() - t_runfft;

		// Calculate magnitude of complex numbers output by the FFT.
		t_magfft = HAL_GetTick();
		arm_cmplx_mag_f32(samples, magnitudes, FFT_SIZE);

		//magnitudes[0] = 0;

		/*
		  arm_max_f32(magnitudes, FFT_SIZE/2, &maxValue, &maxIndex);

		  opti_freq = maxIndex * DELTA_F;

		  arm_max_f32(magnitudes, FFT_SIZE/4, &maxValue, &maxIndex);

		  opti_freq_below = maxIndex * DELTA_F;

		  t_magfft = HAL_GetTick() - t_magfft;
		 */

		//printf("Optifreq below 20kHz: %d, Optifreq: %d, maxIndex: %d\n", opti_freq_below, opti_freq, maxIndex);

		t_fft = HAL_GetTick() - t_fft;

		t_storage = HAL_GetTick();

		/*
		num_freq_bunch = 0;
		for (i=0; i<FFT_SIZE/4; i++) {
			if (magnitudes[i] > 15000) {
				opti_freq_table[num_freq_table] = i;
				mag_bunch_table[num_freq_table++] = magnitudes[i];
				num_freq_bunch++;
			}
		}
		index_freq[num_sample_bunch] = num_freq_bunch;
		 */

		t_storage = HAL_GetTick() - t_storage;

		//opti_freq_table[num_sample_bunch] = opti_freq_below;
		//opti_freq_amplitude[num_sample_bunch] = maxValue;

		// Build spectrogram
		for (i=0; i < MAX_INDEX_FREQ; i++) {
			mag_spectrogram[i][num_sample_bunch] = magnitudes[i];
		}


	}

	t_bunch = HAL_GetTick() - t_bunch;

	//printf("Time: %d     %d      %d     %d\n", t_bunch, t_acq, t_fft, t_storage);

	/*
	printf("opti_freq_table: ");
	for (i=0; i<2*BUNCH_SAMPLE_SIZE; i++) {
		printf("%d ", opti_freq_table[i]);
		opti_freq_table[i] = 0;
	}
	printf("\n");
	for (i=0; i<2*BUNCH_SAMPLE_SIZE; i++) {
		printf("%d ", mag_bunch_table[i]);
		mag_bunch_table[i] = 0;
	}
	printf("\n");
	for (i=0; i<BUNCH_SAMPLE_SIZE; i++) {
		printf("%d ", index_freq[i]);
		index_freq[i] = 0;
	}
	printf("\n");
	 */

	KNN();

	if (!no_bird)
		nb_songs_per_bird[bird_index] += 1;

#if RETRIEVE_NB_SONGS_PER_BIRD
	store_FLASH();
#endif

	//printf("Mean frequency: %1.0f, bird index: %d\n", mean_f, bird_index);
	printf("Mean frequency: %1.0f\n", mean_f);
	printf("Number of songs per bird: %d pigeons, %d blackbirds, %d great tits, %d blue tits\n", nb_songs_per_bird[0], nb_songs_per_bird[1], nb_songs_per_bird[2], nb_songs_per_bird[3]);

	print_bird();

	/*
	  //printf("opti_freq_table amplitude: ");
	  for (i=0; i<BUNCH_SAMPLE_SIZE; i++) {
		  printf("%1.0f ", opti_freq_amplitude[i]);
	  }
	  printf("\n");
	 */

	//printf("%d\n ", HAL_GetTick());
}

void print_bird()
{
	if (no_bird) {
		printf("No bird detected\n");
	} else {
		switch (bird_index)
		{
		case 0:
			printf("A pigeon has been detected\n");
			break;
		case 1:
			printf("A blackbird has been detected\n");
			break;
		case 2:
			printf("A great tit has been detected\n");
			break;
		case 3:
			printf("A blue tit has been detected\n");
			break;
		}
	}
}

void KNN(void)
{
	// Extract the weighted mean frequency from mag_spectrogram
	MeanFrequency();

	// Refill temp_freq_range by birds_freq_range
	for (i=0; i < N_BIRDS; i++) {
		for (j=0; j < N_SONGS; j++) {
			temp_freq_range[i][j] = birds_freq_range[i][j];
		}
	}

	// Find the indexes of the frequencies nearest to mean_f and store in close_freq_index
	for (k=0; k < KNN_SIZE; k++) {
		close_freq_index[k] = 11;
		temp_delta_freq = 1e8;
		for (i=0; i < N_BIRDS; i++) {
			for (j=0; j < N_SONGS; j++) {
				if (temp_freq_range[i][j] - mean_f < temp_delta_freq && temp_freq_range[i][j] - mean_f > -temp_delta_freq) {
					temp_delta_freq = temp_freq_range[i][j] - mean_f;
					if (temp_delta_freq < 0)
						temp_delta_freq = -temp_delta_freq;
					i_end = i;
					j_end = j;
				}
			}
		}
		temp_freq_range[i_end][j_end] = 1e8;
		close_freq_index[k] = i_end;
	}

	/*
	printf("\n");
	for (i=0; i<KNN_SIZE; i++) {
		printf("%d ", close_freq_index[i]);
	}
	printf("\n");
	*/

	// Compute the number of index occurences for each bird, store in
	for (i=0; i < N_BIRDS; i++) {
		KNN_bird_indexes_number[i] = 0;
	}
	for (k=0; k < KNN_SIZE; k++) {
		KNN_bird_indexes_number[close_freq_index[k]] += 1;
	}

	max_number_songs = 0;
	for (i=0; i < N_BIRDS; i++) {
		if (KNN_bird_indexes_number[i] > max_number_songs) {
			bird_index = i;
			max_number_songs = KNN_bird_indexes_number[i];
		}
	}
}

void MeanFrequency(void)
{
	// sum_mag_spectrogram: mean of magnitudes for each frequency over the whole time frame
	for (i=0; i < MAX_INDEX_FREQ; i++) {
		sum_mag_spectrogram[i] = 0;
		for (j=0; j < BUNCH_SAMPLE_SIZE; j++) {
			sum_mag_spectrogram[i] += mag_spectrogram[i][j];
		}
	}

	for (i=0; i < MAX_INDEX_FREQ; i++) {
		sum_mag_spectrogram[i] *= sum_mag_spectrogram[i];
	}


	min_mag = 1e26;
	for (i=1; i < MAX_INDEX_FREQ; i++) {
		if (sum_mag_spectrogram[i] < min_mag)
			min_mag = sum_mag_spectrogram[i];
	}
	for (i=0; i < MAX_INDEX_FREQ; i++) {
		sum_mag_spectrogram[i] -= min_mag;
	}

	for (i=0; i < MAX_INDEX_FREQ; i++) {
		sum_mag_spectrogram[i] -= sound_correction[i]*1e7; // Remove constant background sound
	}

	min_mag = 1e26;
	for (i=10; i < MAX_INDEX_FREQ; i++) {
		if (sum_mag_spectrogram[i] < min_mag)
			min_mag = sum_mag_spectrogram[i];
	}
	for (i=0; i < MAX_INDEX_FREQ; i++) {
		sum_mag_spectrogram[i] -= min_mag;
	}


	// sum_mag: sum of magnitudes for the whole time frame (frequency and time)
	sum_mag = 0;
	for (i=1; i < MAX_INDEX_FREQ; i++) {
		sum_mag += sum_mag_spectrogram[i];
	}


	// mean_f: weighted mean frequency over the whole time frame
	mean_f = 0;
	for (i=2; i < MAX_INDEX_FREQ; i++) {
		mean_f += sum_mag_spectrogram[i] * i * DELTA_F / sum_mag;
		//printf("%1.0f ", sum_mag_spectrogram[i]/1e7);
	}

	// max_mag: max magnitude has to be > threshold
	max_mag = 0;
	for (i=2; i < MAX_INDEX_FREQ; i++) {
		if (sum_mag_spectrogram[i] > max_mag)
			max_mag = sum_mag_spectrogram[i];
	}
	no_bird = 0;
	if (max_mag/1e7 < FREQ_MAG_TRESH) {
		no_bird = 1;
	}
}


void store_FLASH()
{
	/* Unlock the Flash to enable the flash control register access *************/
	if (HAL_FLASH_Unlock() == HAL_ERROR)
		printf("Error in HAL_FLASH_Unlock\n");

	__HAL_FLASH_CLEAR_FLAG(0xFFFF);

	/* Erase the user Flash area
	    (area defined by FLASH_USER_START_ADDR and FLASH_USER_END_ADDR) ***********/

	/* Get the 1st sector to erase */
	//FirstSector = GetSector(FLASH_USER_START_ADDR);
	/* Fill EraseInit structure*/
	//EraseInitStruct.TypeErase     = TYPEERASE_SECTORS;
	//EraseInitStruct.VoltageRange  = VOLTAGE_RANGE_3;
	//EraseInitStruct.Sector        = FirstSector;
	//EraseInitStruct.NbSectors     = N_BIRDS;
	//if (HAL_FLASHEx_Erase(&EraseInitStruct, &SECTORError) != HAL_OK)
	//{
		/*
	      Error occurred while sector erase.
	      User can add here some code to deal with this error.
	      SECTORError will contain the faulty sector and then to know the code error on this sector,
	      user can call function 'HAL_FLASH_GetError()'
		 */
	//	printf("Error in FLASH program init\n");
	//}

	/* Note: If an erase operation in Flash memory also concerns data in the data or instruction cache,
	     you have to make sure that these data are rewritten before they are accessed during code
	     execution. If this cannot be done safely, it is recommended to flush the caches by setting the
	     DCRST and ICRST bits in the FLASH_CR register. */
	//__HAL_FLASH_DATA_CACHE_DISABLE();
	//__HAL_FLASH_INSTRUCTION_CACHE_DISABLE();

	//__HAL_FLASH_DATA_CACHE_RESET();
	//__HAL_FLASH_INSTRUCTION_CACHE_RESET();

	//__HAL_FLASH_INSTRUCTION_CACHE_ENABLE();
	//__HAL_FLASH_DATA_CACHE_ENABLE();

	/* Program the user Flash area word by word
	    (area defined by FLASH_USER_START_ADDR and FLASH_USER_END_ADDR) ***********/

	Address = FLASH_USER_START_ADDR;

	for (i=0; i < N_BIRDS; i++)
	{
		//nb_songs_per_bird[i] = 3;
		if (HAL_FLASH_Program(FLASH_TYPEPROGRAM_WORD, Address, 0) == HAL_OK)
		{
			Address = Address + 4;
		}
		else
		{
			/* Error occurred while writing data in Flash memory.
	         User can add here some code to deal with this error */
			uint32_t e = HAL_FLASH_GetError();
			printf("Error in FLASH program\n");
		}
	}

	/* Lock the Flash to disable the flash control register access (recommended
	     to protect the FLASH memory against possible unwanted operation) *********/
	if (HAL_FLASH_Lock() == HAL_ERROR)
		printf("Error in HAL_FLASH_Lock\n");

}

void read_FLASH()
{
	Address = FLASH_USER_START_ADDR;

	for (i=0; i < N_BIRDS; i++)
	{
		data32 = *(__IO uint32_t *)Address;
		Address = Address + 4;
		nb_songs_per_bird[i] = data32;
	}
}

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


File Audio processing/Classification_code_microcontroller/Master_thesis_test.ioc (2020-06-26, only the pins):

Mcu.UserName=STM32L072CZYx
PA1.GPIO_Label=PA1_RESERVED
PA1.Signal=GPIO_Output
PA10.Signal=USART1_RX
PA12.GPIO_Label=PA12_RESERVED
PA12.Signal=GPIO_Output
PA15.GPIO_Label=PA15_RESERVED
PA15.Signal=GPIO_Output
PA2.Signal=ADC_IN2
PA3.Signal=ADC_IN3
PA5.Signal=GPIO_Output
PA6.GPIO_Label=PA6_RESERVED
PA6.Signal=SPI1_MISO
PA7.GPIO_Label=PA7_RESERVED
PA7.Signal=SPI1_MOSI
PB0.GPIO_Label=PB0_RESERVED
PB0.Signal=GPXTI0
PB1.GPIO_Label=PB1_RESERVED
PB1.Signal=GPXTI1
PB3.GPIO_Label=PB3_RESERVED
PB3.Signal=SPI1_SCK
PB4.GPIO_Label=PB4_RESERVED
PB4.Signal=GPXTI4
PB5.Signal=USART1_CK
PB6.Signal=USART1_TX
PC0.GPIO_Label=PC0_RESERVED
PC0.Signal=GPIO_Output
PC1.GPIO_Label=PC1_RESERVED
PC1.Signal=GPIO_Output
PC13.GPIO_Label=PC13_RESERVED
PC13.Signal=GPXTI13
PC2.GPIO_Label=PC2_RESERVED
PC2.Signal=GPIO_Output
PH0-OSC_IN.Signal=RCC_OSC_IN
PH1-OSC_OUT.Signal=RCC_OSC_OUT

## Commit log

2020-05-22 Add simulation files
    [AEM10941_Configuration_tool_REV1.1.xlsx, BOM Martin Braquet.xlsx, DFEG12060D-8R2M=P3--3DModel-STEP-46669.STEP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]
2020-05-24 Add BOM
    [BOM Martin Braquet.xlsx]
2020-06-06 Update source code and simulation files
    [BOM Martin Braquet.xlsx, current_consumption_FFT.xlsx]
2020-06-26 Add MCU code + presentation videos
    [Master_thesis_test.cfg]

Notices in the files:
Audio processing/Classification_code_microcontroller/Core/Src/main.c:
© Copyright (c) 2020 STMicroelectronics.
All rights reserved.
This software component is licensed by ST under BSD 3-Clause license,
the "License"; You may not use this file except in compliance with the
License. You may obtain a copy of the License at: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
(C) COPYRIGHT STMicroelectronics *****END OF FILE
